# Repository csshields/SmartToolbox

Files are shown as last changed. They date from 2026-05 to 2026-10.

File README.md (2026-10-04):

# SmartToolbox

A toolbox that tells you which drawer a tool is in. Say what you are looking for, and
the box answers on its screen and lights the row of drawers to open.

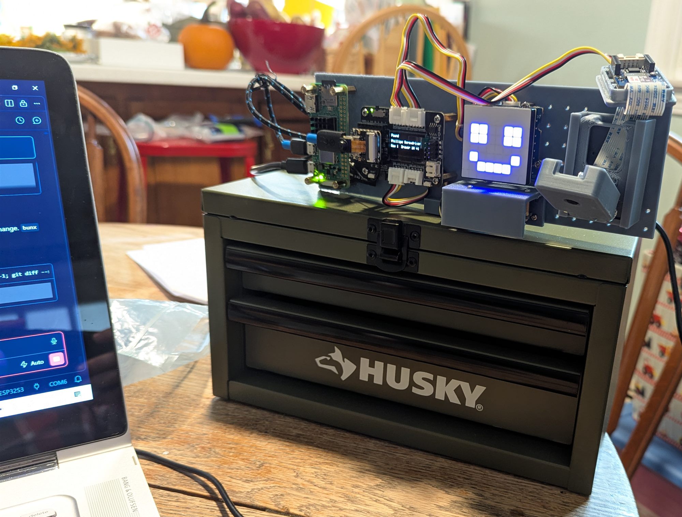
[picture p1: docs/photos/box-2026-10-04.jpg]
The SmartToolbox mounted on a Husky two-drawer chest, its screen naming a found Phillips screwdriver and its LED matrix showing a smiling face


*The build as of October 2026. More photos in [docs/photos](docs/photos/).*

## How it works

1. **Ask.** Hold the button and speak, or say **"Hi ESP"** and then the tool's name.
2. **Listen.** A Seeed XIAO ESP32S3 records the audio and sends it over USB to a
   Raspberry Pi Zero 2.
3. **Transcribe.** The Pi has the audio transcribed by Whisper, running on a NAS or
   through OpenAI, and matches what was said against the tools it knows -
   "where are my needle nose pliers" finds *Needle-Nose Pliers*.
4. **Answer.** The box shows the drawer on its OLED (for example `Row 1, Drawer 1A`),
   lights that row on its 8x8 LED matrix and LED strip, and its face reacts while it
   listens, thinks, and answers.

## What works today

| Feature | State |
|---|---|
| Voice lookup - button, speech, drawer on screen and lit | Working |
| "Hi ESP" wake word | Working since firmware 0.28.0 |
| Several toolboxes, each with its own drawers and light rows | Working |
| Web dashboard for toolboxes, drawers, tools and settings | Working |
| Firmware updates over Wi-Fi (OTA) | Working |
| Recovery flashing over USB from the Pi | Working |
| Recognising common tool names on the box itself, skipping Whisper | Planned |
| Waking up when someone walks up (PIR sensor) | Planned - the sensor is wired, nothing reads it yet |
| Noticing which tools leave and return (camera) | Blocked - needs a trained vision model |

The spec keeps a status tag on every section, and
[docs/HARDWARE.md](docs/HARDWARE.md) records what each physical part is doing.

## The dashboard

The Pi serves a web dashboard on port 3000:

- **Dashboard** - the tools in each drawer of a toolbox, with request history.
- **Toolboxes** - add toolboxes and drawers, edit a drawer's name, label and light row,
  and choose which box the device is mounted on.
- **Devices** - the XIAO's firmware version, last contact and recent activity.
- **AI Settings** - where speech goes to be transcribed.

A copy of the dashboard running on a development machine has its own database, and
shows a **Local copy** badge so it is not mistaken for the real box.

## Hardware

- Seeed XIAO ESP32S3 Sense (on-board microphone) on the Expansion Board Base for XIAO,
  which carries the OLED and the push-to-talk button
- Raspberry Pi Zero 2, connected to the XIAO by USB
- Grove 8x8 RGB LED matrix and Grove WS2813 LED strip
- Grove PIR motion sensor and Grove Vision AI V2 (wired, not yet used)
- 3D-printed mounting plate and brackets, in [cad/](cad/)

Pins, wiring, and the state of every part are in [docs/HARDWARE.md](docs/HARDWARE.md).

## Repository layout

```
smarttoolbox/
├── api/                 # Bun + TypeScript server and dashboard (runs on the Pi)
│   ├── src/             # Server, SQLite database, serial link, transcription
│   ├── public/          # Dashboard pages - plain HTML, CSS and JS, no build step
│   ├── scripts/         # Firmware release, USB flashing, device commands
│   ├── deploy/          # systemd service for the Pi
│   └── sync.ps1         # Deploys the server to the Pi
├── firmware/            # Arduino sketch for the XIAO ESP32S3
├── cad/                 # Printed parts, with the source that generates them
└── docs/                # Hardware record, plans, sources and photos
```

## Getting started

### Run the server locally

```bash
cd api
bun install
bun run start    # http://localhost:3000
bun test
```

On Windows the serial link to the box does not start, so the server and dashboard run
fine with nothing attached - against their own local database.

### Deploy to the Pi

```powershell
cd api
.\sync.ps1           # copy the server to the Pi and restart it
.\sync.ps1 -Status   # service status and the end of its logs
```

### Firmware

The sketch builds with `arduino-cli` against the pinned versions in
`firmware/smarttoolbox/sketch.yaml`. Releases go out over Wi-Fi:

```powershell
cd api\scripts
.\release-firmware.ps1 -Version x.y.z -Push -Now   # the device fetches it within a minute
.\flash-device.ps1 -Version x.y.z                  # over USB, when OTA cannot help
```

A change to the flash partition table, such as the one that made room for the wake
word, can only be installed over USB.

## Documentation

- [.github/copilot-instructions.md](.github/copilot-instructions.md) - the project spec:
  architecture, database, every endpoint, the serial protocol, and debugging.
- [docs/HARDWARE.md](docs/HARDWARE.md) - every part, its pins, and whether it works.
- [docs/](docs/) - implementation plans (`PLAN-*.md`), each with its current status.
- [firmware/README.md](firmware/README.md) - firmware setup.

## License

[MIT](LICENSE). The vendored Grove matrix driver in `firmware/smarttoolbox/` keeps
Seeed's own MIT licence, alongside it.

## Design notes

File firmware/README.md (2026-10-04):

# SmartToolbox Firmware

Arduino firmware for the Seeed XIAO ESP32S3 Sense that sits on the toolbox. It listens
for a request, sends the audio to the Pi over USB serial, and shows the answer on the
OLED, the 8x8 matrix and the LED strip.

Pins, wiring and the state of every part are in [docs/HARDWARE.md](../docs/HARDWARE.md).
The hardware traps worth knowing before changing anything are in
[.github/instructions/xiao-esp32s3-firmware.instructions.md](../.github/instructions/xiao-esp32s3-firmware.instructions.md).

## Hardware

- **Board**: Seeed XIAO ESP32S3 Sense, seated in the Expansion Board Base for XIAO
- **Carrier**: the Expansion Board Base brings the OLED (SSD1306, 0x3C), the
  push-to-talk button on D1, an RTC, an SD slot, and four Grove ports
- **Microphone**: the Sense board's PDM mic (GPIO 42 clock, GPIO 41 data). It feeds
  both push-to-talk and the "Hi ESP" wake word, and needs `PSRAM=opi` in the build
- **Indicators**: Grove 8x8 RGB LED matrix on a Grove I2C port; Grove WS2813 LED strip
  on the UART port, data GPIO44
- **Wired, not yet used**: Grove PIR motion sensor on the A0/D0 port (GPIO1), and the
  Grove Vision AI V2 on a Grove I2C port (0x62)
- **Link to the Pi**: USB serial to a Raspberry Pi Zero 2

## Building

The sketch builds with `arduino-cli`. `smarttoolbox/sketch.yaml` pins the ESP32 core
(3.3.11) and every library, and is the default profile, so a plain compile uses those
exact versions rather than whatever is installed on the machine:

```powershell
arduino-cli compile firmware/smarttoolbox
```

Libraries, all pinned in `sketch.yaml`:

- `ArduinoJson` - the serial messages
- `U8g2` - the OLED
- `Adafruit NeoPixel` - the WS2813 strip

The Grove matrix driver is not in the Arduino library registry, so it is vendored into
the sketch folder (`grove_two_rgb_led_matrix.*`). `ESP_SR` (the wake word), `ESP_I2S`,
`WiFi`, `HTTPClient` and `Update` ship with the ESP32 core.

`smarttoolbox/partitions.csv` replaces the board's default flash layout to make room
for the 3.3 MB speech model the wake word needs. Arduino picks it up from the sketch
folder automatically.

## Getting a build onto the device

Normally over Wi-Fi, from the `api/scripts` folder:

```powershell
.\release-firmware.ps1 -Version x.y.z -Push -Now   # the device fetches it within a heartbeat
.\flash-device.ps1 -Version x.y.z                  # over USB from the Pi, when OTA cannot help
```

Over-the-air updates need working firmware to receive them, and cannot change the
partition table. A bad build, or a partition change, goes on with `flash-device.ps1`,
which flashes through the XIAO's ROM bootloader over the USB cable it already shares
with the Pi. The `firmware-release` skill in `.claude/skills/` walks through all three.

Bump `FIRMWARE_VERSION` in `smarttoolbox.ino` for every release; the device compares it
with what the Pi offers.

## Talking to the Pi

The XIAO and the Pi exchange newline-delimited JSON over USB serial at 115200 baud. The
Pi sees the XIAO as `/dev/ttyACM0` and the `smarttoolbox` service opens it on start.
The device sends a `device/status` heartbeat every 30 seconds, which is how the Pi
knows it is alive and how it hands over queued commands such as "check for firmware".

To watch it:

```bash
tail -f ~/smarttoolbox/logs/service.log
```

```text
[serial] request id=status-12 endpoint=device/status
[serial] response written id=status-12
```

If the XIAO is unplugged, reset, or reflashed, the serial link reconnects on its own
with a growing backoff capped at 5s - no service restart needed. The full protocol is
in the spec.

## Project structure

```
firmware/
├── smarttoolbox/
│   ├── smarttoolbox.ino            # The firmware
│   ├── sketch.yaml                 # Pinned core and library versions
│   ├── partitions.csv              # Flash layout, with room for the speech model
│   ├── grove_two_rgb_led_matrix.*  # Vendored matrix driver
│   ├── arduino_secrets.example.h   # Template - copy to arduino_secrets.h
│   └── arduino_secrets.h           # Wi-Fi and device key (gitignored)
└── README.md                       # This file
```

`arduino_secrets.h` must live beside the sketch: Arduino resolves `#include "..."`
from the sketch folder only.

### Arduino Cloud leftovers

`Untitled_apr15a.ino`, `motion_ino.ino`, `thingProperties.h`, `sketch.json`, and
`ReadMe.adoc` sit in `firmware/` and are **history, not live code**. They came from
an early Arduino Cloud project and nothing builds or references them.
`motion_ino.ino` is the one worth keeping for now: it is the PIR + OLED bring-up
sketch, and its `U8G2_SSD1306_128X64_NONAME_F_HW_I2C` constructor is where the
working OLED setup came from. The rest can be deleted whenever you like.

## TODO

- [x] USB serial link to the Pi, with lookups and a heartbeat
- [x] Push-to-talk voice lookup
- [x] "Hi ESP" wake word (0.28.0)
- [x] Wi-Fi OTA updates, and USB recovery flashing
- [ ] Recognise common tool names on the device, skipping Whisper
- [ ] Read the PIR on GPIO1 (wired, no firmware)
- [ ] Talk to the Grove Vision AI V2 (needs a trained model first)

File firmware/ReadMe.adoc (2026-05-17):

:Author: shieldsfam01
:Email:
:Date: 15/04/2026
:Revision: version#
:License: Public Domain

= Project: {Project}

Describe your project

== Step 1: Installation
Please describe the steps to install this project.

For example:

1. Open this file
2. Edit as you like
3. Release to the World!

== Step 2: Assemble the circuit

Assemble the circuit following the diagram layout.png attached to the sketch

== Step 3: Load the code

Upload the code contained in this sketch on to your board

=== Folder structure

....
 sketch123                => Arduino sketch folder
  ├── sketch123.ino       => main Arduino file
  ├── schematics.png      => (optional) an image of the required schematics
  ├── layout.png          => (optional) an image of the layout
  └── ReadMe.adoc         => this file
....

=== License
This project is released under a {License} License.

=== Contributing
To contribute to this project please contact: 

=== BOM
Add the bill of the materials you need for this project.

|===
| ID | Part name      | Part number | Quantity
| R1 | 10k Resistor   | 1234-abcd   | 10       
| L1 | Red LED        | 2345-asdf   | 5        
| A1 | Arduino Zero   | ABX00066    | 1        
|===

=== Help
This document is written in the _AsciiDoc_ format, a markup language to describe documents. 
If you need help you can search the http://www.methods.co.nz/asciidoc[AsciiDoc homepage]
or consult the http://powerman.name/doc/asciidoc[AsciiDoc cheatsheet]

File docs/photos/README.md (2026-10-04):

# Photos

Photographs of the box as it was built, one file per occasion, named
`<what>-<yyyy-mm-dd>.jpg`. Resize to about 2000 px on the long side before
committing - a phone's full-size original is several megabytes and the repo
keeps every version forever.

| Photo | Shows |
|---|---|
| `wiring-2026-09-02.jpg` | The 2026-09-02 rewire, every Grove port populated. The wiring that `docs/HARDWARE.md` describes. |
| `box-2026-10-04.jpg` | The latest build, mounted on the Husky two-drawer box: Pi Zero 2 on the left, the XIAO on its expansion base with the OLED showing a found Phillips screwdriver, the 8x8 matrix smiling, and the Vision AI V2 in its printed cradle on the right. Taken the day "Hi ESP" was first proven. |

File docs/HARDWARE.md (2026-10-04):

---
title: Hardware - parts, bring-up status, and pin mappings
scope: the single record of what is in the box, what physically works, and which pin carries it
status: active
updated: 2026-09-13
---

# SmartToolbox Hardware

Every part owned, whether it physically works, and which pin carries it.
`.github/copilot-instructions.md` remains the project spec; it points here instead of
repeating any of this. The same status convention applies - see Document Conventions in
the spec - and note the spelling difference it records: a section carries
`**Status: ...**`, a component entry carries `**Status**: ...` with the asterisks closed.

Photographs of the box live in `docs/photos/`, dated, with an index there.
`wiring-2026-09-02.jpg` shows it as wired below; `box-2026-10-04.jpg` is the latest
build, mounted on the toolbox. When the words and a photograph disagree, check the
photograph's date before trusting either.

Firmware traps that are about *behaviour* rather than parts - touch sensor v2 semantics,
the first ten `touchRead` calls after boot, upload settings - live in
`.github/instructions/xiao-esp32s3-firmware.instructions.md`, which loads by file glob
when a sketch is open. Which pin carries what is here; how it misbehaves is there.

## The 2026-09-02 rewire

The box was taken apart and rebuilt on 2026-09-02. Everything below the bring-up table
describes the result. What changed, because several of these had been treated as fixed
constraints for weeks:

- **The Vision AI V2 came off the expansion header** and is now cabled to a Grove I2C
  port. It was never mechanically required to stack; that was convenience, and Seeed's
  own documentation offers the Grove route.
- **The Expansion Board Base took the header instead**, which is what unblocked every
  GPIO part in one move.
- **The Grove I2C Hub and the Grove Red LED Button came out of the box entirely.** The
  hub is unnecessary now the base carries two I2C ports, and the button was the
  mis-wired part that had been disturbing the bus.
- **The Grove OLED came off** in favour of the base's own screen, which the firmware
  drove with no change at all.
- **The WS2813 strip and the PIR are wired for the first time.**
- **The touch pad stopped being the trigger**, because the PIR now drives that pin. The
  base's button replaced it.

## Bring-Up Status

Updated 2026-09-02, with the Grove Base Hat row added 2026-09-06. This table is the
single place to check what is physically working. Each row is a summary; the detail
lives in the section named beside it.

| Component | Status | Notes |
|---|---|---|
| XIAO ESP32S3 Sense | Verified | Seated in the Expansion Board Base with the Sense board still mated on top. LED on GPIO21, active-low |
| Expansion Board Base | Verified | On the expansion header. Carries the OLED, the button, an RTC and an SD slot, and all four Grove ports now in use |
| USB serial XIAO to Pi | Verified | Unchanged by the rewire. The XIAO's own USB-C stays exposed with the base fitted |
| Wi-Fi OTA updates | Verified | Device pulled and installed 0.24.0. Signal measured at -52 dBm on 2026-09-02, so the external antenna is fitted and working. **Without it the radio cannot associate** |
| OLED | Verified | The base's own SSD1306 at 0x3C, on the shared bus. It replaced the Grove SSD1315, which answered at the same address - the two cannot both be on the bus. Same U8g2 constructor, no firmware change |
| Grove 8x8 matrix | Verified | On one of the base's Grove I2C ports, no longer through the hub. Mounted a quarter turn out, so the firmware sets `DISPLAY_ROTATE_270` every boot - that setting lives on the panel and survives power cycles |
| WS2813 LED strip | Verified, under-volted | Pointed at a real drawer row on 2026-09-02, in 0.27.0. Data is GPIO44; see the strip section for how that was proven and why the supply is a problem |
| Push-to-talk button | Verified | The base's own button on D1, shipped in 0.24.0. Hold-to-talk confirmed end to end on 2026-09-02: press, speak, release, drawer on the screen and the row on the strip |
| Microphone (PDM, on the Sense board) | Verified for Whisper and the wake word | Reported ready on the 0.24.0 boot and carries speech to Whisper. Since 0.28.0 it also feeds ESP-SR, and **"Hi ESP" fired on hardware on 2026-10-04.** **Known thin:** the audio sits at 4-10% of full scale (that capture's rms was 52) - enough for WakeNet up close, and the first suspect if it stops firing from further away. Detail and the DC-bias trap are under Microphone |
| PIR motion sensor | Wired, no firmware | On the base's A0/D0 Grove port, so its signal is GPIO1. **Nothing in the firmware reads it.** No longer blocked, merely unwritten |
| Grove Vision AI V2 link | Cabled, unused | Moved from the expansion header to a Grove I2C cable. No firmware has ever talked to it - there is no SSCMA include in the sketch and no such library in `sketch.yaml` |
| SenseCraft model | Not deployed | **Blocks Feature 3.** Nothing to detect until a model is trained and flashed |
| Camera (OV2640, on the Sense board) | Not initialised | Physically fitted and facing up. The sketch carries no camera driver. Tool identification is the Vision AI V2's job, not this camera's |
| Grove I2C Hub | Removed | Out of the box. The base's two I2C ports made it unnecessary |
| Grove Red LED Button | Removed | Out of the box. It was mis-wired into the I2C hub, where its switch pulled on lines the displays depend on. The base's own button does its job now |
| Touch pads | Unused | Still on the board and still touch-capable, but nothing reads them. GPIO1 carries the PIR |
| Grove Base Hat for Pi Zero | Owned, not fitted | Added to the list 2026-09-06. Never mounted, never powered, no software has addressed it. It would occupy the Pi's 40-pin header |
| Pi 40-pin GPIO header | Free, unpopulated | 26 usable GPIO, nothing in this project uses them. `gpioget`/`gpiomon` are installed and `/dev/gpiochip0` is present. The Grove Base Hat above is what would take it |
| Mounting magnets | Owned, not fitted | Added to the list 2026-09-13. Six 12 x 3 mm neodymium discs, intended to hold the back plate to the toolbox. Nothing holds them yet, and **the toolbox has not been checked for steel** - see Mechanical |

## Hardware Platform

**Main Controller**: Seeed **XIAO ESP32S3 Sense** (not the plain XIAO ESP32S3 - see
`docs/xiao-screenshot.PNG` for the exact part)

- **MCU**: Espressif ESP32-S3
- **Connectivity**: Wi-Fi and BLE are available; the box connects to the Pi Zero 2 over **wired USB serial** (USB-C, CDC/ACM). Wi-Fi is used only for OTA updates.
- **Memory**: 8MB PSRAM, 8MB flash. **PSRAM is on as of 2026-08-28**, and was off before that: a bare `esp32:esp32:XIAO_ESP32S3` takes the first entry of every board menu, and for PSRAM that is `disabled`, so `ps_malloc` returned null in every binary this repo had released. The fqbn now lives in `firmware/smarttoolbox/sketch.yaml` as the default `release` profile, so `release-firmware.ps1` and a bare `arduino-cli compile firmware/smarttoolbox` both pick it up; verify with `arduino-cli compile --show-properties`, where the bare fqbn shows an empty `build.defines` and the corrected one shows `-DBOARD_HAS_PSRAM`. **A manual `arduino-cli` invocation that bypasses the profile must carry `:PSRAM=opi` itself** - the microphone buffer cannot be allocated without it, and the failure presents as a dead mic rather than a build error.
- **Power**: 3.3V from the Pi's USB feed, through the base.

**Physical stack, as rebuilt 2026-09-02.** Three boards, three different connectors:

```
   Sense board          camera (OV2640) + PDM mic, facing up
        |               board-to-board connector
   XIAO ESP32S3         the core board
        |               expansion header
   Expansion Board Base OLED, button, RTC, SD, four Grove ports
```

The Vision AI V2 used to occupy the bottom slot and now hangs off a Grove cable instead.
The Sense board has never been in competition with anything: it mates through the XIAO's
own board-to-board connector, not the expansion header. This is the one place the stack
is described; everything else refers back to it.

**Expansion Board Base for XIAO with Grove OLED**, SKU 103030356

The carrier the XIAO plugs into, and the part that resolved the GPIO question. It brings
its own 0.96 inch SSD1306 OLED at 0x3C, a user button on D1, a buzzer on A3, a microSD
slot with chip select on D2, and a PCF8563 real-time clock at 0x51. It has a LiPo
connector, a charging circuit and a power switch, none of which this project uses -
**but the switch is a new way for the box to look dead, so check it first when nothing
happens.** The XIAO's own USB-C stays accessible with the base fitted; seat the XIAO
first, then plug the cable.

**Footprint, for the back plate**: the board is 58 x 42.5 mm with a 3.0 mm hole at each
corner, on a 50 x 35 mm rectangle - 4.0 mm in from the short edges and 3.75 mm from the
long ones. The v5 plate had these as M2 holes on a 50.8 x 38.1 pattern, measured by hand
on the assumption the board was imperial; both were wrong, and the board would not bolt
down. v6 in `cad/` uses the figures above, at 3.4 mm to leave the print some slack.

**Grove port allocation.** All four are in use, which is the whole budget:

| Port | Carries | Pins |
|---|---|---|
| I2C (1) | Grove Vision AI V2 | Shared bus, GPIO5/GPIO6 |
| I2C (2) | Grove 8x8 RGB matrix | Shared bus, GPIO5/GPIO6 |
| UART | WS2813 LED strip | GPIO44 data, GPIO43 backup |
| A0/D0 | Grove PIR motion sensor | GPIO1 |

**Every Grove port on this base supplies 3.3V**, which is silkscreened on the board. That
is correct for everything here except the strip, which wants 5V - see below.

**Vision Hardware**: Seeed Grove Vision AI Module (V2), SKU 101021112, + OV5647 Camera

- **Connection**: Grove I2C cable to the base, since 2026-09-02. It answers at address 0x62. Seeed documents both the header and the Grove route; stacking was convenience, not a requirement.
- **Onboard MCU**: Himax WiseEye2 (capable of on-device ML inference)
- **Storage**: 32GB microSD card on the module itself
- **Library**: `Seeed_Arduino_SSCMA`, which **this project has never used.** The link has been verified with other software; no shipped firmware has ever addressed the module.

**Owned, not in the box**

- **Grove I2C Hub (6 Port)**: removed 2026-09-02, unnecessary now the base has two I2C ports.
- **Grove Red LED Button**, SKU 111020044: removed 2026-09-02. It is a passive switch and LED with no I2C chip, and it had been plugged into the I2C hub, where its two pins landed on SDA and SCL and pressing it disturbed the bus. The base's own button replaced it.
- **Grove OLED Display 0.96 inch (SSD1315)**: removed 2026-09-02, displaced by the base's own screen at the same I2C address.

**API Server**: Raspberry Pi Zero 2

- **CPU**: Broadcom BCM2710A1 (ARM Cortex-A53 @ 1GHz, quad-core)
- **Memory**: 512MB RAM
- **Storage**: MicroSD card (16GB+ recommended)
- **OS**: Raspberry Pi OS Lite (64-bit recommended)
- **Connectivity**: WiFi 802.11n, Bluetooth 4.2
- **Power**: 5V via micro-USB (2.5A minimum recommended)
- **GPIO**: 40-pin header, entirely unused. 26 usable pins; libgpiod installed. A Grove Base Hat for it is owned and not fitted - see below.
- **Purpose**: Host the Bun API server, the SQLite database, and the dashboard, and process tool identification requests.

### Grove Base Hat for Raspberry Pi Zero

Seeed Grove Base Hat for Raspberry Pi Zero, SKU 103030276. **Owned as of 2026-09-06 and
never fitted.** It has not been mounted, powered, or addressed by any software, so every
fact below comes from Seeed's documentation rather than from this box. Treat the whole
section as a lead until something here has been checked against the part.

It is the Pi-side answer to the question the Expansion Board Base answered on the XIAO
side: it turns a bare 40-pin header into Grove ports. It is the Pi Zero form factor, so
it fits the Zero 2, and it keeps 24 pins passed through.

- **Port count is disputed by the vendor's own pages.** Seeed's product title advertises 1 I2C, 1 UART, 2 digital, 4 analog and 1 PWM; Seeed's wiki for the same board lists three analog ports, labelled A0, A1 and A2. **Count them on the board before designing against them.**
- **The Grove ports are 3.3V**, and the wiki says plainly that 5V Grove modules will not work on it. **This does not solve the WS2813 supply problem.** The strip still needs its own regulated 5V, and it could not move to the Pi in any case - see the strip section, where the timing comes off the ESP32's RMT peripheral.
- **The analog ports are not GPIO.** They land on an onboard 12-bit ADC that the Pi reads over I2C, so an analog part costs a bus transaction rather than a pin. The chip is an STM32F030F4P6 on older boards and an MM32F031F6P6 on newer ones, and **the two answer at different addresses, 0x04 and 0x08.** The product page for this SKU says MM32. `i2cdetect -y 1` settles it, and it is the first thing to run once the hat is on.
- **Pin mapping, from the wiki and unverified against the part**: digital on BCM 5 and 16, PWM on BCM 12 and 13, UART on BCM 14 and 15, and the I2C port straight onto the Pi's own bus.
- **The UART Grove port is the Pi's serial console** by default, so anything plugged in there needs the console disabled first. The XIAO link is USB CDC and is not affected by this.
- **Nothing in this project needs it yet.** Every part that wanted a GPIO is on the XIAO, and the 2026-09-02 rewire freed the header that had been blocking them. What the hat buys is a second place to put a plain digital or analog part, now that the XIAO's four Grove ports are fully allocated. It is also a third answer to the constraint discussed under the MCP23017 in `docs/PLAN-drawer-activity.md` - though that plan dropped per-drawer switches over the cost of a magnet and a wire run on every drawer, which having somewhere to plug them does not change.

## Sensors & Peripherals

### WS2813 LED strip - the row indicator

Grove WS2813 RGB LED Strip Waterproof, 30 LED/m, 1m, SKU 104020108. On the base's UART
Grove port.

- **Data is GPIO44 (D7). The backup line is GPIO43 (D6).** Proven on hardware 2026-09-02 by a firmware bring-up that drove each pin in turn in a different colour and let the strip say which one it answered on. Neither Seeed's wiki nor the connector markings settled it, and Grove UART cables differ over which signal sits on pin one.
- **The pixel that lights at power-up is the boot ROM.** The ROM prints its log on GPIO43 before the sketch starts, that pin is the strip's backup input, and a WS2813 falls back to the backup line when the main one is idle. The first write from the firmware clears it. This is not a fault and it was visible long before any strip code existed.
- **Nothing in the firmware uses UART0**, so the pins are free. `Serial` is the native USB CDC port.
- **Library**: `Adafruit NeoPixel`, pinned in `sketch.yaml`. It drives the timing from the ESP32's RMT peripheral, which is why this works on the XIAO and would not have worked from a Grove port on the Pi.
- **Power is the open problem.** The base's Grove ports supply 3.3V and a WS2813 wants 5V, so the strip runs under-volted: colours skew, the top of the brightness range is missing, and the blue that lights most readily is the one with the most headroom. It works well enough to prove the wiring. **Before the strip is mounted it should get its own regulated 5V supply with a shared ground**, sized for up to 1.8A at full white, because thirty LEDs drawing through the XIAO's regulator on the Pi's USB feed is not a supply, it is a fuse waiting to be found.
- **Brightness is deliberately low** in firmware for the same reason. Raise it only after the supply is sorted.
- **Row mapping is a placeholder.** Row N lights LED N-1. Which LED ends up beside which drawer is a physical decision nobody has made, because the strip is still coiled on the bench.
- **Status**: **working.** In 0.27.0 a spoken lookup lights the LED beside the matching row. First proven 2026-09-02 by asking for a Phillips head screwdriver and watching LED 1 come up white, white being what a record with no confidence gets.

### Push-to-talk button

The Expansion Board Base's own button, on **D1 (GPIO2)**. It shorts the pin to ground
with no pull-up on the board, so the firmware holds it high internally and a press reads
LOW. Hold it, speak, release.

- **It replaced the D0 touch pad**, which the PIR now drives. Touch charges a pad while the sensor drives it, which is two drivers on one net.
- **The touch machinery went with the pad**: seven pads of baseline calibration, a trigger ratio, a warm-up discard, and a per-scan debug print, all of which existed to make a capacitive pad behave the way a button simply does. The traps they taught are still recorded in the firmware instructions, because the pads remain on the board.
- **Watch for it reading permanently pressed.** D1 is plausibly the second signal pin of the A0/D0 Grove port the PIR sits on. Single-signal Grove modules leave that pin unconnected, so it should be clear, but a box that starts recording on its own and never stops is that.
- **Status**: shipped in 0.24.0, confirmed on hardware 2026-09-02.

### Microphone (on board)

The XIAO's own digital microphone, on the **Sense expansion board**. No external part is
needed or planned.

- **Interface**: PDM. Pins are fixed by the board, confirmed against Seeed's own documentation: **GPIO 42 = clock, GPIO 41 = data.**
- **Sample Rate**: 16 kHz mono, 16-bit. Not a preference - the ESP32-S3 supports *only* PDM mono at 16-bit, so the bit width and slot mode are the chip's, not a choice. The rate is adjustable; Seeed reports 16 kHz as the stable one, and it is also what Whisper wants, so there is no reason to move it.
- **Library**: `ESP_I2S.h` from the installed esp32 core (3.3.11), *not* the core-2.x `I2S.h` that Seeed's published examples still lead with. The two have different APIs and picking the wrong page is the likely first failure:

```cpp
// Core 3.x - what this project has.
I2S.setPinsPdmRx(42, 41);
I2S.begin(I2S_MODE_PDM_RX, 16000, I2S_DATA_BIT_WIDTH_16BIT, I2S_SLOT_MODE_MONO);
```

- **Two ways to read, and they are not interchangeable.** `recordWAV(seconds, &size)` returns a `ps_malloc`'d buffer with a WAV header already attached, but takes a fixed duration - fine for a bring-up, useless for hold-to-talk, where the length is not known when recording starts. That path reads in a loop instead and lets the Pi write the header. See `docs/PLAN-mic-bringup.md` and `docs/PLAN-voice-lookup.md`.
- **Buffers go in PSRAM.** Four seconds of 16 kHz 16-bit mono is 128 KB against the XIAO's 320 KB of SRAM, of which this sketch already uses 49 KB.
- **The mic rides on a positive DC bias.** Samples run roughly +981 to +2568 and never cross zero, so RMS must be taken about the mean - measuring raw samples reads the offset, not the sound. Corrected in 0.17.0. A DC-corrected RMS read 17 in a quiet room against 210 spoken into, on 2026-08-29.
- **It feeds two consumers now, and they do not share.** Since 0.28.0 ESP-SR's feed task reads this same `I2SClass` continuously for the wake word, and the recording loop takes it back for the duration of a capture. Both traps that follow from that - draining the pause rather than trusting it, and the `portMAX_DELAY` the feed task leaves on the shared object - are in `.github/instructions/xiao-esp32s3-firmware.instructions.md`.
- **Status**: carrying speech since 0.20.0, voice lookup shipped in 0.22.0. Wake word written in 0.28.0 and **proven on hardware 2026-10-04**: "Hi ESP" started a capture that Whisper transcribed as "screwdriver". **Known thin:** the audio sits at 4-10% of full scale, with no gain applied and the DC offset not stripped. That was tolerable for Whisper and turned out to be enough for WakeNet at close range. It is still the weakness that makes the box mis-hear "screwdriver", and the first thing to look at if the wake word gets unreliable with distance.

### PIR motion sensor (Grove PIR Sensor, SKU 101020020)

- **Connection**: the base's A0/D0 Grove port, so the signal is **GPIO1 (D0)**. Wired 2026-09-02.
- **Type**: passive infrared, digital output, HIGH on motion. 3.3V-5V from the Grove port.
- **Detection Range**: configurable, typically 3-7 meters.
- **Board**: 40 x 20 mm, with three 2.2 mm mounting holes, **all centred on the board's edge** inside small round ears. Two are on the long edges, 10 mm from the connector end and 20 mm apart. The third is on the centreline of the sensor end. The PIR element itself sits 13.3 mm from the board centre, towards that end. These figures come from Seeed's Eagle board file for v1.2 (see `docs/SOURCES.md`). An earlier guess of two holes 5 mm in from each end was wrong, and so was the first bracket built on it.
- **Bracket**: `pir_bracket.stl`, reshaped 2026-09-27 and **not yet printed**. Seen from the side it is a C, open at the bottom: the upright bolts to the plate, a shelf runs forward off its top, and a hood hangs down the front. The board screws under the shelf facing down, inside the 26 mm channel, so the hood blocks the view forward into the room and the sensor looks down at the drawers. Nothing hangs below the plate's bottom edge, so nothing gets in the way of the top drawer. A PIR sees warm, moving things, so what it catches at the drawers is the hand and arm, not the drawer itself.
- **Status**: **wired and unread.** No firmware touches GPIO1. Feature 1 is no longer blocked on hardware; it is simply unwritten.

### Vision: Grove Vision AI Module (V2) + OV5647 Camera

- **Resolution**: OV5647, up to 5MP (2592x1944)
- **Connection**: Grove I2C cable to the base, address 0x62.
- **Identification Method (default)**: on-device inference on the module's WiseEye2 MCU via a model deployed through **SenseCraft AI** (no-code; supports MobileNet V1/V2, EfficientNet-lite, YOLOv5/v8). Only the label and confidence are read - Seeed's hardware cannot serve a live frame and results over the link at the same time. A cloud vision model remains a fallback, but it needs raw frames pulled a different way: the module's own SD card or its Type-C port.
- **Enclosure**: a printed three-part holder - base, tilting cap, camera holder - taken from Thingiverse rather than drawn here. Source and licence are under Printed parts in `docs/SOURCES.md`; it is CC BY-SA, so merging its geometry into a part of ours would carry that licence across. **It is superglued to the back plate.** The plate is on its sixth revision and will be reprinted again, and every reprint means breaking that bond or losing the enclosure, so a cradle bolting to the plate's 10 mm grid is the better fixing - see `cad/`.
- **Status**: **connected and unused.** No model is deployed, and no firmware in this repo has ever addressed the module. Both have to change before Feature 3 means anything.

### Camera (OV2640, on board)

On the Sense board, facing up. **No firmware has ever initialised it** and the sketch
carries no camera driver. Tool identification runs on the Vision AI V2's own camera and
MCU, so this one has no assigned job.

### IMU (external, TBD)

- **Type**: 6-axis (3-axis accelerometer + 3-axis gyroscope), I2C
- **Status**: no part selected, nothing bought. **Library**: TBD.

### Displays

**OLED**: the base's onboard 0.96 inch SSD1306 at 0x3C, on the shared I2C bus. Shows
status and exact drawer labels such as `1A` and `3`. Driven with U8g2
(`U8G2_SSD1306_128X64_NONAME_F_HW_I2C`).

**8x8 RGB matrix**: Grove, on a Grove I2C port. Six positions represent rows 1-6; row 1
is a single shared indicator for drawers 1A, 1B and 1C. Its address is discovered at boot
and confirmed against the VID, so a missing panel degrades rather than hangs. Superseded
in the long run by the strip - see the Row Indication decision.

**Camera illumination LED**: planned, not owned, not wired.

## Pin Mappings

**Status: Implemented** - every pin below is wired and confirmed on hardware, except
where the entry says otherwise.

```cpp
// Onboard user LED. Active-low: LOW turns it ON, HIGH turns it OFF.
#define LED_PIN           LED_BUILTIN   // GPIO21

// Push-to-talk: the expansion base's own button, switch to ground.
const uint8_t BUTTON_PIN = 2;           // D1

// WS2813 strip on the base's UART Grove port. DIN is the RX pin; the boot ROM's
// log lands on the TX pin, which is the strip's backup input.
const uint8_t STRIP_DATA_PIN = 44;      // D7, UART0 RX
//                              43      // D6, UART0 TX - backup in, driven by no one

// PDM microphone on the Sense board. Fixed by the board, not chosen.
#define MIC_CLOCK_PIN     42
#define MIC_DATA_PIN      41

// PIR motion sensor on the base's A0/D0 Grove port. Wired, and read by nothing.
//   GPIO1 (D0)

// I2C, shared by everything on the base's two Grove I2C ports plus the base's own
// devices. `Wire.begin()` needs no arguments.
//   SDA = D4 (GPIO5), SCL = D5 (GPIO6)
//   0x3C OLED (on the base)      0x51 RTC (on the base, unused)
//   0x62 Grove Vision AI V2      matrix address discovered at boot
```

### Also spoken for

The base wires these whether or not the firmware uses them, so treat them as taken:
**D2** is the microSD chip select, **A3** is the buzzer, and **D8/D9/D10** are the SPI
bus the SD slot sits on. The buzzer is the only sound hardware this project owns.

### Deliberately Absent

- **No per-row LED GPIO pins.** Row indication is the strip on a single data line, and the matrix over I2C. Earlier drafts defined `ROW_LED_1`..`ROW_LED_6`; those defines should not reappear.
- **No touch pad defines.** The pads are still on the board and nothing reads them.
- **No per-drawer sensors.** Drawer open/close detection is one of three candidate methods in Feature 3 and no hardware has been chosen.

## Resolved: the GPIO expansion question

**Closed 2026-09-02.** For weeks this section asked where the PIR and a button could
possibly go, on the premise that the Vision AI V2 owned the expansion header and could
not be moved. Both halves of that premise were wrong, and the correction cost a Grove
cable:

- **The module did not need to stack.** It is an I2C peripheral at 0x62 and Seeed's own documentation offers the Grove route. The proof was already sitting in the old build, where the I2C hub chained off the module's own Grove port - the bus was coming back out of that connector the whole time.
- **The header was better spent on the Expansion Board Base**, which turns one occupied slot into four Grove ports, a button, a screen and a clock.

Two earlier corrections in this section are worth keeping, because both had been shaping
decisions:

- **GPIO never had to come from the XIAO.** The Pi's 40-pin header is unused. That option was never taken, but it was the observation that unstuck the thinking.
- **The Sense board never competed with anything.** It mates through the XIAO's own board-to-board connector. An earlier revision of the spec claimed otherwise and that claim drove decisions for weeks.

What is still constrained: the base has one digital Grove port and the PIR has it, so
another digital part means the Pi's header, a soldered wire, or the buzzer's pin. As of
2026-09-06 the first of those has a Grove-shaped answer sitting unused in a drawer - see
the Grove Base Hat for Raspberry Pi Zero above.

## Decision: row indication runs on the strip, driven from the XIAO

**Status: Partial** - decided 2026-08-28, moved to the XIAO 2026-09-02, code written and
not yet released. **This reverses the earlier decision to drive the strip from the Pi
over SPI**, which was made when the XIAO's expansion header looked unavailable. Once the
base freed a real GPIO, the Pi route lost every argument it had:

- The ESP32 generates WS2812 timing in its RMT peripheral. On the Pi the same job needs either a native addon this project does not want inside Bun, or a bit-banging trick over SPI on a pin that is not a Grove port.
- The protocol argument was a wash. The Pi route needed no new message because the Pi computes the `rows` array; the XIAO route needs none either, because that array is already delivered to the device and already lights the matrix.
- One fewer moving part, and the strip lights from the same code path as every other indicator.

The reason for using a strip at all is unchanged. The 8x8 matrix indicates a row by
lighting matrix row N for toolbox row N, which has two faults that are the same fault
seen from two sides:

- **It caps at eight.** The unit of meaning is the panel's own height, so a toolbox with more rows than the panel has cannot be addressed. `MAX_TOOLBOX_ROWS` is 8 for this reason - a symptom of the design, not a hardware limit worth keeping.
- **It is hard to read.** A single lit row gives the eye no scale to count against, so it reads as "higher" or "lower" rather than as row 3.

The strip removes both by not encoding position at all. One LED sits beside each row, so
the light **is** the answer. Thirty LEDs is thirty rows.

**What this does to the other outputs.** Each ends up with one job and no overlap:

| Output | Job |
|---|---|
| WS2813 strip | Points at the row, physically |
| 8x8 matrix | The face: idle, thinking, not found, not understood |
| OLED | Names the exact drawer - `1A` against `1B`, which the strip cannot distinguish |

The lit-row phase is already gone - a result goes straight to the digit, because the
strip is the spatial cue now. Once the strip is mounted the matrix stops encoding
numbers at all, so the digit phase can go too. Do not invest further in making the
matrix legible as a row indicator.

## Mechanical

The printed parts - the back plate, the PIR bracket and the Vision AI cradle - are
generated by `cad/build_plate.py`, which is their source of record. The plate is
228.6 x 76.2 x 3.0 mm with a 10 mm grid of M2 clearance holes; the bottom two rows of
that grid run on to the right edge so the PIR bracket can bolt anywhere along the
bottom. Component footprints that the CAD depends on are recorded with their component
above - the expansion board's is under Expansion Board Base.

### Mounting magnets

- **What is owned**: six neodymium disc magnets, 12 mm diameter x 3 mm thick. Grade not
  marked, so treat the pull as roughly 2 kg each until something says otherwise. Four
  would mount the plate and two are spare.
- **They cannot sit in the plate.** The magnet is 3 mm thick and the plate is 3.0 mm
  thick, so there is no pocket to cut. They go in `magnet_bar.stl` instead: a 20 x 76.2
  x 4.8 mm bar that bolts to the back of the plate and carries a magnet near each end.
  Two bars, one per plate end, put four magnets near the plate's four corners. It is
  one part printed twice - the bar is symmetric about its own centreline, so the left
  and the right are the same STL.
- **Each pocket is 0.2 mm shallower than the magnet**, so the magnet stands proud and
  touches the steel. Plastic between magnet and steel is an air gap, and an air gap
  costs pull far faster than a thicker wall would. The bolt pilots are blind for the
  same reason: a screw tip breaking through would hold the magnet off.
- **Where the bars bolt, and why those columns.** Grid rows 25 and 45, on columns 44 and
  184. 184 is the rightmost full grid column - the rail past it carries rows 5 and 15
  only, too short a base for a 76 mm bar. 44 is the leftmost column with room for a
  screw head: the Pi ends at 34.5 and the expansion board starts at 52. That column is
  the only thing v6 gained for this; the right bar bolts to holes that existed in v5.
- **Budget the pull as shear, not pull.** The plate hangs on a vertical surface, so the
  magnets work in shear, which holds on the order of a fifth of the rated figure - and
  the rated figure assumes thick ground steel rather than thin painted toolbox sheet.
  Against the 300-400 g the loaded plate weighs, four of these is comfortable; one is
  not.

### Feet

`foot.stl`, printed twice, **drawn 2026-09-27 and not yet printed.** The alternative
to the magnets: the plate stands on top of the toolbox rather than hanging on its side,
landscape, Pi end on the left.

- **The plate leans back 8 degrees** in a 3.4 mm slot. The lean is what holds it: the
  plate rests against a 22 mm triangle behind, and a 6 mm lip in front only stops the
  bottom edge sliding forward. The slot is loose on purpose, so nothing depends on
  friction or on how accurately the plate printed.
- **The tilt is kept slight** because the PIR and the camera tip back with the plate.
  At 8 degrees both still look down at the drawers.
- **The plate stands at the lid's front edge.** The PIR looks straight down from about
  16 mm in front of the plate, so the plate has to be near the edge for the sensor to see
  past the lid to the drawers. That is why the front of the foot is only 6 mm deep and
  the heel behind is 35. It also means the
  forward tipping margin is small: the camera and the PIR sit in front of the plate. If
  the plate tips forward, raise `FOOT_TILT` before lengthening the toe.
- **Where they go**: plate x 62-92 and 196-226. That keeps them clear of both magnet-bar
  columns, so feet and bars can be tried together. It also clears the PIR bracket at
  119-169 and the expansion board's screw heads at x 56 and 106.

## Open items

1. **A 5V supply for the strip**, with a shared ground. Until then it stays dim and
   under-volted.
2. **Mount the strip and fix the row mapping.** `STRIP_ROW_FIRST_LED` and the row-to-LED
   arithmetic are placeholders until the physical layout exists.
3. **Give the microphone some gain.** The audio sits at 4-10% of full scale with the DC
   offset not stripped, and it mis-hears: "screwdriver" came back from Whisper as "We're
   screwing driver" on 2026-09-02, and the box correctly found nothing for it. The fix is
   Step 1 of `docs/PLAN-mic-bringup.md`, and it is now the weakest link in the box.
   **Raised in importance 2026-09-06:** the 0.28.0 wake word runs WakeNet on this same
   signal, and WakeNet is fussier than Whisper. If "Hi ESP" needs shouting, this is why,
   and this is the fix - not the recording path.
4. **Say "Hi ESP" at the box.** The 0.28.0 wake word is written, compiles, and has never
   been heard by anything. It needs a partition change, so it goes on over USB with
   `flash-device.ps1` and cannot arrive over the air. Say it **twice** - the second time
   is the test, because ESP-SR disables itself after every detection and a missing re-arm
   looks exactly like a dead microphone.
5. **Read the PIR.** It is wired and nothing looks at it, which is all that stands
   between here and Feature 1.
6. **Deploy a SenseCraft model**, without which the Vision AI V2 is a connected part with
   nothing to say.
7. **Check the toolbox is actually steel**, before any more design goes into magnet
   mounting. A fridge magnet against the spot the plate will sit answers it. Plenty of
   toolboxes are aluminium or plastic-skinned, and the whole approach dies if this one
   is.

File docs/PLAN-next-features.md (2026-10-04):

---
title: Plan of Attack - Next Four Features
scope: implementation plan, written 2026-08-27
status: partially complete - Features 1, 2 and 3 are done; 4 is not started
---

> **Features 1, 2 and 3 shipped 2026-08-27.** Read those sections below as history,
> not as work outstanding. Feature 4 (dashboard search) is still an accurate
> description of unstarted work.
>
> Feature 1 (serial reconnect) needed a follow-up the plan did not anticipate: the
> reconnect worked, but the tty came up in cooked mode with echo, so the device
> received nothing back. See Communication Protocol in the spec.
>
> Feature 2 (touch-triggered lookup) took three hardware bugs beyond what is described
> here - the S3's touch readings rise rather than fall, scanning all nine pads froze the
> peripheral, and the startup baseline averaged unusable boot readings. All three are
> recorded in `.github/instructions/xiao-esp32s3-firmware.instructions.md`.
>
> Also built the same day, and not part of this plan: Wi-Fi OTA updates, see
> `PLAN-ota-updates.md`.

# Plan of Attack

Four features, ordered. Each is independent except where noted — you can implement any
one without the others, but the ordering below minimizes wasted effort.

| # | Feature | Size | Touches | Hardware needed |
|---|---|---|---|---|
| 1 | Serial reconnect | Small | API | None |
| 2 | Touch-triggered lookup | Medium | Firmware + API | XIAO only (already verified) |
| 3 | Delete endpoints | Small | API + dashboard | None |
| 4 | Dashboard search | Small | Dashboard | None |

**Recommended order: 1 → 2**, then 3 and 4 in either order. Feature 1 is first because
every `arduino-cli upload` resets the board and re-enumerates the USB device, which
kills the Pi's serial stream. Without reconnect, every firmware iteration in Feature 2
costs a `sudo systemctl restart smarttoolbox`. Doing 1 first pays for itself within an
hour of Feature 2 work.

If you want a lighter second item instead, swap Feature 2 for 3 or 4 — nothing depends
on ordering beyond the note above.

---

## Shared conventions

Read `.github/copilot-instructions.md` first; it is the project spec and is current as
of 2026-08-27.

**Code style**
- TypeScript strict mode is on (`api/tsconfig.json`). No `any` — the codebase casts
  request bodies to explicit inline types instead, e.g.
  `await readJsonBody(req) as { name?: string }`.
- The router in `api/src/index.ts` is a plain `if` chain on `pathname` and
  `req.method`, not a framework. Hono is a dependency but is **not** used for routing.
  Match the surrounding pattern; do not introduce Hono to add a route.
- All SQL lives in `api/src/db.ts` as prepared statements declared at module scope.
  Parameterized queries only (`?1`, `?2`).
- Errors propagate as thrown `Error`s from `db.ts`, and `index.ts` maps the message to
  a status code — see the `message === 'Drawer not found.' ? 404 : 400` pattern at
  `api/src/index.ts:427`. Keep that pattern rather than inventing an error class.
- Every mutating route calls `writeRequestLog(...)`, which both persists to
  `request_logs` and console-logs. Follow it; the dashboard's Recent Requests panel
  reads that table.
- Comments are sparse in this codebase and explain *why*, not *what*. Match that.

**Testing**
- `bun test` from `api/`. Two test files exist: `serialProtocol.test.ts` and
  `serialTransport.test.ts`, both using `import { expect, test } from "bun:test"`.
- There is **no `test` script in `package.json`** — add
  `"test": "bun test"` to `scripts` as part of Feature 1.

**Running**
- `cd api && bun run start` → `http://localhost:3000`.
- On Windows the serial listener does not start (`SERIAL_DEVICE` is unset off Linux),
  so the HTTP API and dashboard run fine with no XIAO attached.
- Deploy to the Pi: `cd api && .\sync.ps1`. Add `-Status` to see service status and the
  tail of both logs.

**Documentation is part of done.** `.github/copilot-instructions.md` uses per-section
status tags (`**Status: Implemented | Partial | Planned | Blocked**`). Each feature
below lists which tags and checklists to update. Update them in the same commit as the
code — that convention is the whole point of the tags.

---

## Feature 1 — Serial reconnect

### Why

`api/src/serialTransport.ts:22` opens the device exactly once:

```ts
const input = createReadStream(options.devicePath);
const output = createWriteStream(options.devicePath, { flags: "a" });
```

When the XIAO is unplugged, reset, or reflashed, the read stream errors or closes and
never comes back. `README.md` currently documents the workaround: restart the service.
That workaround is the thing being deleted.

### Design

Wrap the stream creation in a `connect()` function and drive it from a small state
machine:

- `connect()` creates both streams, wires handlers, and resets the line buffer.
- On `error` **or** `close`/`end` from either stream: tear down both, then schedule a
  reconnect. Guard with a flag so `error` followed by `close` schedules only once.
- Backoff: start at 500ms, double on each failure, cap at 5s. Reset to 500ms once a
  connection successfully delivers data.
- `close()` must set a `stopped` flag and clear any pending reconnect timer, otherwise
  tests and shutdown hang.
- **Reset `SerialLineBuffer` on every reconnect.** A partial line captured before an
  unplug is garbage and would corrupt the first message after reconnect.
- A missing device (`ENOENT`, XIAO not plugged in at boot) is the same case as a
  disconnect — retry, do not throw. This also means the service can start before the
  XIAO is attached.

### Make it testable

The current signature takes `devicePath` and calls `fs` directly, which cannot be
tested without hardware. Add optional injection:

```ts
openStreams?: (devicePath: string) => { input: Readable; output: Writable };
retryDelaysMs?: number[];   // default [500, 1000, 2000, 4000, 5000]
```

Default to the real `fs` implementation. Tests pass fake streams (`PassThrough`) and
`[1, 1]` delays, so no fake timers are needed.

### Steps

1. Add `"test": "bun test"` to `api/package.json` scripts.
2. Refactor `startSerialTransport` into `connect()` + reconnect scheduling, keeping the
   exported signature backward compatible (all new options optional).
3. Add `onConnect` / `onDisconnect` optional callbacks alongside the existing
   `onError` and `onResponseWritten`.
4. Wire the new callbacks in `api/src/index.ts:534` to log
   `[serial] connected` / `[serial] disconnected, retrying in Nms`.
5. Extend `serialTransport.test.ts`: the existing `SerialLineBuffer` test stays; add
   coverage for (a) reconnect after an input error, (b) buffer reset across reconnect,
   (c) `close()` cancelling a pending retry.

### Gotchas

- The `input.on("data", async ...)` handler at `serialTransport.ts:26` is async but data
  events are not queued — two chunks arriving quickly can interleave responses. Out of
  scope here, but do not make it worse; note it if you touch that path.
- Writing to a disconnected device can throw synchronously as well as emit `error`.
  Wrap the `output.write` call.

### Done when

- Unplug the XIAO mid-run, replug it, press `RST`, and `[serial] request id=boot-1`
  appears in the log with no service restart.
- `bun test` passes.
- `README.md` "USB Serial Check" section: delete the restart-required paragraph.
- `.github/copilot-instructions.md`: tick "Serial reconnect" in Phase 2 of Development
  Priorities.

---

## Feature 2 — Touch-triggered tool lookup

### Why

This is the first time the system does its actual job. Every piece already works in
isolation: touch pads are verified on hardware, the serial handshake reaches the Pi,
and `tools/lookup` is implemented end to end on the API side. Nothing has ever
connected them.

No new hardware. No microphone, no SenseCraft model, no I2C hub.

```
touch pad → tools/lookup over serial → SQLite → response → LED blinks row number
```

A touch pad is a stand-in for the microphone that does not exist yet. Each pad maps to
a hardcoded tool name; this is a bench harness for the real voice flow in Feature 2 of
the spec, not the finished interaction.

### Prerequisite: seed the database

The lookup returns nothing useful against an empty database. Before bench testing,
create a drawer and a tool from the dashboard, matching the real box (see Physical
Layout in the spec): e.g. drawer `1A` in row 1 containing "phillips screwdriver".
The firmware's hardcoded query must match a tool name exactly — see the matching
caveat under Feature 4.

### API side (small)

One change, in `api/src/index.ts:158`:

`handleSerialLine` currently returns an error response for **any** unparseable line.
The firmware also emits human-readable debug output on the same wire
(`Serial.print("Touched GPIO: ")` in the current sketch), so every debug line would
generate an error response written back to the device — noise generating noise.

Rule to implement:

- Line does not start with `{` after trimming → **ignore silently**. It is device debug
  output, not a request.
- Line starts with `{` but fails to parse → return the existing error response. A
  malformed request is still a bug worth reporting.

Add a test in `serialProtocol.test.ts` or a new test covering both branches.

### Firmware side

Current state: `firmware/smarttoolbox/smarttoolbox.ino` in the working tree is the
touch/LED bring-up sketch. The committed version is the boot handshake. This feature
merges them.

1. **Add ArduinoJson** via Library Manager. Update the checklist in the spec's
   Libraries Required section.
2. **Restructure `loop()` to be non-blocking.** The bring-up sketch ends with
   `delay(50)`, which starves serial reads. Convert to a `millis()`-based poll
   interval, keeping the existing debounce (2 consecutive samples) and the
   startup-calibrated touch baselines — that calibration is deliberate, see
   `.github/instructions/xiao-esp32s3-firmware.instructions.md`.
3. **Map pads to tools.** A small array parallel to `TOUCH_PINS`, e.g. pad D0 →
   `"phillips screwdriver"`. Only map as many pads as you have seeded tools.
4. **Send the request.** Monotonic id counter (`req-1`, `req-2`, ...):
   ```json
   {"id":"req-1","type":"request","endpoint":"tools/lookup","body":{"query":"phillips screwdriver"}}
   ```
   One line, newline-terminated. Note `body` is required by the parser even when empty.
5. **Read the response.** Mirror `SerialLineBuffer`: accumulate `Serial.read()` bytes
   until `\n`, then parse with ArduinoJson. Match on the echoed `id`; ignore responses
   whose id you are not waiting for. Time out after ~2s and treat as not-found.
6. **Blink feedback.** The LED is active-low (`LOW` = on). There is no matrix yet, so
   encode the result in blink count:
   - found → blink `rows[0].rowNumber` times, slow
   - not found (`found: false`, HTTP 200 — a miss is not an error) → 3 fast blinks
   - timeout or error response → 1 long blink

   Document in a comment that this stands in for the 8x8 matrix.
7. **Remove or gate the periodic debug prints** so they do not flood the protocol
   channel. The API-side rule above tolerates them, but they are still noise.

### Response shape to parse

```json
{"id":"req-1","success":true,"body":{
  "found": true,
  "tool": "Phillips Screwdriver",
  "drawers": [{"drawerId":1,"label":"1A","rowNumber":1,"quantity":2,
               "confidence":null,"observedAt":null}],
  "rows": [{"rowNumber":1,"certainty":null}]
}}
```

`confidence` and `certainty` are `null` for manually entered tools that the camera has
never observed. Do not assume they are numbers.

### Gotchas

- **Serial baud is 115200** and the board re-enumerates on reset — Feature 1 is what
  makes this tolerable.
- ArduinoJson document sizing: the response above is comfortably under 512 bytes for a
  single drawer, but a tool in several drawers grows it. Use `JsonDocument` (v7) which
  sizes dynamically, or budget 1KB.
- Touch baselines are captured in `setup()`. If a pad is being touched at boot the
  baseline is wrong — worth a serial warning, not a fix.

### Done when

- Touching a mapped pad blinks the LED the correct number of times for a seeded tool.
- Touching it for an unseeded tool gives 3 fast blinks.
- `[serial] request id=req-N endpoint=tools/lookup` appears in the Pi log.
- Spec updates: Hardware Bring-Up Status table (add a row for the touch-triggered
  lookup path), Phase 2 checklist ("Make the firmware send real requests" — adjust
  wording since this is `tools/lookup`, not `vision/observe`), and Feature 2's status
  line to note the bench harness exists.

---

## Feature 3 — Delete endpoints

### Why

The API has no `DELETE` route at all. A drawer created with a typo is permanent, and
the only recovery is deleting the SQLite file. `ON DELETE CASCADE` is already in the
schema and `PRAGMA foreign_keys = ON` is set at `api/src/db.ts:62`, so the database
side is ready.

### Steps

1. **`api/src/db.ts`** — two functions mirroring the existing style:
   - `deleteDrawer(drawerId: number): boolean` — returns whether a row was removed.
   - `deleteTool(drawerId: number, toolId: number): boolean`.

   Declare the `DELETE` statements at module scope with the other prepared queries.
   `bun:sqlite`'s `.run()` returns `{ changes }`; use it rather than a `SELECT` first.

2. **`api/src/index.ts`** — two routes, following the existing regex-match pattern at
   `api/src/index.ts:479`:
   - `/^\/api\/drawers\/(\d+)$/` with `req.method === 'DELETE'`
   - `/^\/api\/drawers\/(\d+)\/tools\/(\d+)$/` with `req.method === 'DELETE'`

   Return `{ success: true }` at 200 on success and 404 when nothing matched. The
   codebase returns JSON bodies everywhere, so prefer that over a bare 204.
   Call `writeRequestLog` in both branches.

3. **Dashboard** — a delete control per drawer and per tool in the Toolbox Inventory
   panel, each behind a `confirm()`. Match the existing inline style.

### Gotchas

- **Cascade is wider than it looks.** `drawer_observations` also has
  `ON DELETE CASCADE` on `drawer_id`, so deleting a drawer destroys its observation
  history, not just its tools. Say so in the confirm dialog — include the tool count.
- Place the `/^\/api\/drawers\/(\d+)$/` match **after** the existing
  `/api/drawers` exact-string checks so it cannot shadow them.

### Done when

- Deleting a drawer removes it and its tools; deleting a tool leaves the drawer.
- Deleting a nonexistent id returns 404, not 500.
- Both actions appear in Recent Requests.
- Spec: add both routes to the HTTP Endpoints table in the API Endpoints section.

---

## Feature 4 — Dashboard search

### Why

There is no search box. The page's own copy at `api/public/index.html:410` says
*"Use the API to search by tool name"* — it is telling the user to go run curl.

### The important caveat

`GET /api/tools/lookup` is an **exact match**, not a substring search:

```sql
WHERE name = ?1 COLLATE NOCASE
```

(`selectCanonicalToolName`, `api/src/db.ts:210`.) Typing "phillips" will **not** find
"Phillips Screwdriver #2". Wiring a search box straight to that endpoint produces a
search that mostly returns nothing.

So this feature is client-side:

**Implement:** filter in the browser over the data the dashboard already has.
`GET /api/drawers` returns every drawer with its full `tools` array, which the page
fetches on load anyway. For a box with 8 drawers this is instant, needs no backend
work, no debounce, and no new endpoint. Filter on tool name and drawer label, and show
the matching drawer's `label` and `rowNumber`.

**Do not** add substring matching to `/api/tools/lookup` as part of this feature — see
below.

### Follow-on, tracked separately: fuzzy lookup

Exact matching is a real problem for the **voice** path, not the dashboard. Whisper
will transcribe "phillips screwdriver" and the database holds "Phillips Screwdriver
#2"; an exact match fails and the toolbox says "not found" for a tool it owns. That
needs `LIKE`/token matching plus a confidence notion in `findToolLocations`, and it
changes the firmware-facing contract.

Keep it out of this feature. Add it to the spec's Planned work so it is not lost — it
should be built alongside Feature 2 of the spec (voice), where it actually matters.

### Steps

1. Add a search input to the Toolbox Inventory panel, matching the existing markup and
   glassmorphism styling.
   **Since 2026-10-04 that panel shows one toolbox at a time**, picked from a dropdown in
   its title. Decide whether a search covers only that box or every box - a tool in
   another box is exactly the one a user cannot find by browsing.
2. Filter the already-fetched drawer list on each keystroke; render matches with drawer
   label, row number, and quantity.
3. Empty query → show everything, the current behavior.
4. No matches → an explicit empty state, not a blank panel.

### Done when

- Typing a partial tool name narrows the list live.
- Clearing the box restores the full list.
- Spec: note the search behavior under Dashboard, and add fuzzy server-side lookup to
  Planned Endpoints with the voice-path rationale.

---

## Not in scope for any of these

Recorded so they are not accidentally pulled in:

- `GET /api/tools/find` and `POST /query` are documented as deprecated in the spec but
  still exist in `index.ts`. Nothing calls either — the dashboard does not, and the
  firmware uses the serial channel. Removing them is a separate cleanup.
- Per-instance tool tracking (`tool_id`, checkout state). The project deliberately
  tracks tools by type and quantity; see Tool Identity in the spec.
- Anything needing the microphone, the SenseCraft model, the I2C hub, or the PIR
  sensor. All four are blocked on hardware — see the Hardware Bring-Up Status table.

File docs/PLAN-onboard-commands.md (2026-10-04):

---
title: Plan of Attack - On-board recognition (the box hears the common ones itself)
scope: implementation plan, written 2026-08-31, revised 2026-09-02 after a source
  review of the pinned core - ESP-SR wake word and a local tool vocabulary carried
  from the Pi, with today's Whisper path as the fallback
status: PHASE 2 PROVEN ON HARDWARE 2026-10-04. A person said "Hi ESP" at the box; it
  recorded its four-second window, Whisper heard "screwdriver" and the lookup resolved.
  That also answers the microphone question Phase 1 was skipped over - the mic is good
  enough for WakeNet, thin signal and all. The log does not separately show a second
  wake in a row, so the re-arm line below is accepted on the person's word, not the log.
  Phase 3 is untouched. Everything ships in 0.28.0 behind a partition change, so it
  arrives over USB or not at all. The 2026-09-02 review against esp32-hal-sr.c corrected
  three claims that were wrong in the first draft; they are marked
  **Corrected 2026-09-02** where they appear.
---

# Plan: the box hears the common tools itself, and only asks Whisper when it is unsure

One sentence of scope:

> Say a wake phrase instead of holding the pad, and a tool the box already knows is
> answered without a Whisper round trip - roughly ten seconds saved - with today's path
> still there for everything else.

## Context, so the plan is honest about where it starts

| Piece | State today |
|---|---|
| Hold-to-talk, `voice/audio`, Whisper | **Works end to end** since 0.22.0 |
| PDM mic, 16 kHz 16-bit mono via `ESP_I2S` | **Works.** This is exactly the format ESP-SR wants - see `mic.begin` in the sketch |
| ESP-SR, prebuilt for the S3 | **Already in the pinned core** (3.3.11), as the `ESP_SR` library plus a prebuilt esp-sr archive. Never compiled into this sketch |
| Speech models (`srmodels.bin`, 3,340,296 bytes) | **Ship with the core.** There is nowhere on the device to put them |
| English MultiNet | **Present.** `CONFIG_SR_MN_EN_MULTINET7_QUANT=y` in the pinned sdkconfig. Worth stating: had it been `SR_MN_EN_NONE`, Phase 3 would be impossible and the wrapper compiles the whole command path out |
| Partition table | `default_8MB`. No `model` partition, and no room for one without redrawing the map |
| Wake word | **Not built.** The spec says out of scope and `PLAN-voice-lookup.md` calls it a separate project. This plan is that project |
| Tool catalogue | 1 tool across 5 drawers in the dev database. Designed here for 400 anyway - see Decision 4 |

## What this buys, stated as a number

Whisper is the slow part and always has been: ~9.3s warm against the NAS, over 30s on the
first call after the container has idled. Both numbers are measured, and they are why
`TRANSCRIBE_TIMEOUT_MS` is 90 seconds.

On-device recognition answers in the time it takes to stop talking.

**The Pi round trip does not go away, and should not be described as if it does.** The
drawer mapping lives in SQLite and the device holds no copy, so a local recognition still
calls `tools/lookup` for the drawer. That call is milliseconds. What is skipped is the
transcription, which is the entire ten seconds.

---

## Is the ten seconds ours to fix, or the NAS's

**Settle this before Phase 1, because it is cheap and it changes the value of everything
below.** This plan spends a partition change that cannot be undone over OTA in order to
remove ~9.3s. That is only a good trade if the 9.3s is irreducible, and nothing measured
so far says it is.

Two specific suspicions, both testable in an afternoon and neither requiring hardware:

- **The >30s first call is container idle, not inference.** A periodic no-op request that
  keeps the Whisper container warm removes that number outright, and it is the number a
  person actually notices - the first lookup of the morning is exactly when the box gets
  judged.
- **9.3s warm for a ~2 second clip is slow for what it is.** It is worth reading what
  model and backend the NAS is actually running. `faster-whisper` on CTranslate2 with
  `base.en` and `beam_size=1` typically returns a clip that short in well under two
  seconds on a NAS CPU.

If those two together take ten seconds to two, the case for Phases 2 and 3 is much
weaker, and the honest answer might be "keep the pad, fix the NAS." **Phase 1 is still
worth doing either way** - the wake word is a separate benefit from the latency, and the
microphone question has to be answered before anyone can plan around it.

Whatever the measurement says, record the number here. Every other claim in this document
carries one.

---

## Decision 1: the wake word is "Hi ESP", and that is a choice about esp-sr, not about the problem

The prebuilt libraries compile exactly one wake word: `CONFIG_SR_WN_WN9_HIESP=y`. The
sdkconfig lists Jarvis, Computer, Alexa, Sophia, Mycroft and a dozen more, every one of
them `is not set`. Enabling a different one means rebuilding `esp32-arduino-libs`; a
phrase of our own - "Smart Toolbox" - means commissioning Espressif to train a model.

Both are out of proportion to the feature. **"Hi ESP" is what esp-sr has on offer.**

**The qualifier matters, and the first draft of this document did not have it.** The
constraint belongs to esp-sr, not to the ESP32-S3. **microWakeWord** - the engine ESPHome
ships - runs TFLite-Micro on this chip, its models are around 100 KB, and custom phrases
are trained with their own Colab notebook plus `piper-sample-generator`. "Smart Toolbox"
is an afternoon there, not a commission.

The catch is that microWakeWord is wake-word-only. It has no MultiNet equivalent, so it
would replace Phase 2 and leave Phase 3 to be built on esp-sr anyway or dropped in favour
of always going to Whisper. That is a real fork, not a free upgrade, and it is the reason
the recommendation here is still esp-sr.

Recorded because it decides whether Phase 2 is worth doing at all, and because the
question will be asked again in six months - at which point "Hi ESP is what is on offer"
would have been quoted back as though no alternative existed.

**Phase 3 does not depend on this.** If "Hi ESP" is unacceptable to live with, keep the
touch pad as the trigger and take the local vocabulary anyway. The ten seconds is in the
transcription, not in the pad.

## Decision 2: the vocabulary comes from the Pi at boot, not from the build

Commands are registered at runtime from plain English strings. `esp32-hal-sr.c` runs
`flite_g2p()` on each phrase on the device, hands the result to
`esp_mn_commands_phoneme_add`, then loads the set with `esp_mn_commands_update()`. The
strings are copied out during `begin()`, so anything we pass can be freed straight after.

So the device asks the Pi for the tool list on boot and registers what comes back. The Pi
keeps owning the vocabulary, exactly as it owns the database, the provider config and the
API key.

**Where the phrases actually live, since it is easy to get this wrong:**

- **On the Pi, permanently** - and no new storage is needed for them. The vocabulary *is*
  the `name` column of the `tools` table. It is already there. The endpoint added in
  Phase 3 is a `SELECT`, not a store.
- **On the XIAO, only in RAM, only while powered.** MultiNet holds the phoneme set in
  memory. Nothing is written to the device's flash, and there is no vocabulary on it to
  go stale - a cold boot has no tool names at all until the Pi supplies them.

That asymmetry is the point: **add a tool in the dashboard, reboot the box, it is
recognised. No firmware release.**

The alternative - baking the list into the sketch as a `const sr_cmd_t[]`, the way the
stock example does - was rejected on that sentence alone. It would make every tool
addition a firmware release, and this project already ships firmware often enough to have
built a USB recovery path for it.

### Register incrementally, and do not build the array at all

The obvious reading of the above - fetch the whole list, build one `sr_cmd_t[400]`, hand
it to `begin()` - is the wrong one, and it is worth saying why before somebody writes it.

`esp_mn_commands_add`, `_phoneme_add`, `_remove`, `_clear` and `_update` are all linked
and all callable from the sketch. Both headers are already on every sketch's include path
in this core - `esp-sr/include/esp32s3` and `esp-sr/src/include` are both in
`flags/includes`, so including `esp_mn_speech_commands.h` needs no path hack. The wrapper
does not expose them, but nothing stops us using them directly:

1. Start SR with no commands at all at boot. The wake word works immediately.
2. Fetch the vocabulary a page at a time - 50 names to a response.
3. `esp_mn_commands_add(id, name)` per name as each page lands.
4. One `esp_mn_commands_update()` at the end.

**What that avoids, in order of how much it matters:**

- **The device is never deaf because the Pi is down.** Registering through `begin()` means
  no vocabulary implies no `begin()` implies no wake word at all. Deaf, not degraded, and
  for a box whose entire job is answering questions that is the worst failure mode
  available. Starting SR before the vocabulary arrives is not an optimisation, it is the
  difference between degrading and dying.
- **The 104 KB command array stops existing.** `sr_cmd_t` is 260 bytes and
  `SR_CMD_STR_LEN_MAX` is 256 - a fifth of internal SRAM to hold strings that are mostly
  padding, on a chip that will also be hosting AFE and MultiNet buffers.
- **The 12 KB JSON line stops existing.** `handleIncomingLine` builds `serialLineBuffer` a
  character at a time into an Arduino `String` on the internal heap, then hands it to a
  `JsonDocument` on the same heap. At 12 KB that is quadratic reallocation, fragmentation,
  and plausibly 30-40 KB of internal SRAM live at once - at exactly the moment SR is
  trying to allocate. 50 names a page is a line the existing transport already handles.
- **`loop()` keeps running between pages.** Heartbeats to the Pi, the OLED, the matrix.
  A single blocking registration of the whole catalogue stops all three for however long
  400 `flite_g2p()` calls take, which is still unmeasured.

### Version the vocabulary, and cache the phonemes against that version

Return a hash of the list alongside it, and store hash plus phonemes in `nvs`. Two things
fall out for almost no work:

- **`flite_g2p` becomes a first-boot cost rather than an every-boot one.** Feed the cached
  phonemes to `esp_mn_commands_phoneme_add` and skip g2p entirely.
- **"Reboot the box" becomes "next heartbeat".** The device already asks the Pi something
  every 30 seconds. Comparing one hash is cheap enough to do there, and re-syncing a
  running model is what the add, remove and update calls are for.

Neither is required for Phase 3 to work. Both are cheap enough that designing the endpoint
without a version field would be the mistake.

## Decision 3: local first, Whisper on anything short of certain - but the fallback is not free

**Corrected 2026-09-02.** The first draft of this section described a fallback that cost
nothing and lost nothing. Both halves were wrong, and the correction changes the design
rather than just the wording.

### What the first draft said, and why it does not hold

The claim was: set `set_det_threshold` high, and anything the model is not sure about
surfaces as `ESP_MN_STATE_TIMEOUT`, which becomes the Whisper trigger - so **"the worst
case is today's behaviour."**

Two problems, both in the core's source:

- **`set_det_threshold` cannot be reached.** It is a function pointer on `esp_mn_iface_t`
  and needs the `model_data` handle. Both live inside the file-static `g_sr_data` in
  `esp32-hal-sr.c`, and there is no getter. Calling `sr_start()` directly does not help -
  it creates the model internally too. The knob the plan was built around does not exist
  at the sketch level.
- **The timeout is a clock, not a confidence signal.** `esp32-hal-sr.c` creates MultiNet
  with a duration argument of 5760. That is the detection window in milliseconds.
  `ESP_MN_STATE_TIMEOUT` does not mean "unsure", it means **5.76 seconds have elapsed
  since the wake word**. By the time it fires the person has long finished speaking, and
  the audio they spoke is gone.

So the real worst case was: today's round trip, **plus** ~5.8 seconds of dead air,
**plus** the box asking them to say it again. That is not today's behaviour, it is
noticeably worse than the touch pad, and it would have been discovered on hardware rather
than on paper.

### What to build instead: tee the audio on its way past

`sr_start()` is declared in the public `esp32-hal-sr.h` and takes a fill callback. The
wrapper's own callback does nothing but read the `I2SClass`. So skip `ESP_SR.begin()`,
call `sr_start()` with our own fill callback, and have it copy each chunk into a PSRAM
ring buffer on its way to the AFE.

Then on `SR_EVENT_TIMEOUT` the last few seconds of audio are already in hand and go
straight to `voice/audio`. **The person says the tool name once.** The fallback costs the
detection window and nothing else, and the original claim - that a miss costs roughly what
was already being paid - becomes true rather than aspirational.

It also removes the I2S race outright: with the tee there is exactly one reader of that
peripheral, forever. See Gotchas.

### The threshold, if it is still wanted

Two ways to get one, and the choice belongs in Phase 1 rather than Phase 3 because it
decides what Phase 3 is:

- **Per-phrase.** `esp_mn_phrase_t` carries a `float threshold`, default 0. Reachable
  through the command list without touching `model_data`.
- **Vendor `esp32-hal-sr.c` into the sketch.** It is Unlicense or CC0, which is the same
  reason the Grove matrix driver is vendored here with a `docs/SOURCES.md` entry. That
  single move buys the model-level threshold, the re-arm fix, the tee, and access to the
  five candidates below - all in one file we control.

### What is given up on a local hit

The underlying result carries up to five candidates with probabilities
(`ESP_MN_RESULT_MAX_NUM`), but the Arduino callback collapses them to one `command_id`.
`matchBestOverlap` deliberately returns every screwdriver and lights every row; a local hit
through the wrapper cannot do that. Letting ambiguity fall through to Whisper, where
`resolveToolQuery` already handles it properly, is still the right default. Vendoring the
hal is the way to stop giving the candidates up, if it turns out to matter.

## Decision 4: 400 is a ceiling on phrases, and the Pi enforces it

`ESP_MN_MAX_PHRASE_NUM` is 400, compiled into the prebuilt archive. Editing the header
does nothing.

**It counts phrases, not tools.** Multiple phrases can share a `command_id`, which is how
"needle nose pliers" and "needle-nose pliers" would both reach one drawer. At 400 tools
that budget is exactly one phrasing each.

So the device takes a list of N and registers it, and **the Pi decides what N is and what
is in it.** Sixty tools or four hundred is the same firmware. If the list ever comes back
over budget the Pi truncates it, ranked, and logs what it dropped - the box degrades
honestly instead of half-registering in silence.

**The Pi should enforce the length limits too, not just the count.**
`ESP_MN_MAX_PHRASE_LEN` is 63 characters and `ESP_MN_MIN_PHRASE_LEN` is 2. Note that
`sr_cmd_t.str` is 256 bytes, so nothing rejects an over-long name until deep inside
`esp_mn_commands_update()`. Checking on the Pi means a bad tool name is visible in the
dashboard next to the tool, rather than inferred from an error list that came back over
serial.

**Storage does not raise the 400 and should not be proposed as a fix.** 400 tool names is
about 12 KB of text; the existing 20 KB `nvs` partition would hold them several times
over. The limit is in the recogniser's search graph. An SD card - and the Sense board has
a slot, and `CONFIG_MODEL_IN_SDCARD` is real in esp-sr, though off in the prebuilt libs -
would only relocate the 3.2 MB model blob off flash. It adds no vocabulary.

The honest reason not to want more than 400 is accuracy, not memory. Closed-set
recognition gets worse as the set grows and tool names crowd together phonetically
("half inch socket" against "half inch wrench"). Decision 3 is what keeps that from being
a user-visible failure.

---

## The partition change

The device's flash is not a folder. It is a fixed map of regions, set at flash time, and
every byte belongs to a region whether anything is in it or not. **Old builds do not
accumulate there** - there are exactly two app slots, permanently, and OTA alternates
between them.

So "full" means over-allocated, not cluttered:

| Region | Reserved | In use |
|---|---|---|
| `app0` | 3,342,336 | 1,091,984 |
| `app1` | 3,342,336 | 1,091,984 |
| `spiffs` | 1,572,864 | nothing - no filesystem code in the sketch |

Roughly 5.8 MB reserved and idle. Redrawing it:

```
# Name,   Type, SubType, Offset,   Size,     Note
nvs,      data, nvs,     0x9000,   0x5000
otadata,  data, ota,     0xe000,   0x2000
app0,     app,  ota_0,   0x10000,  0x250000  # 2,424,832 - 2.2x the current binary
app1,     app,  ota_1,   0x260000, 0x250000
model,    data, spiffs,  0x4B0000, 0x340000  # 3,407,872 - the blob is 3,340,296
coredump, data, coredump,0x7F0000, 0x10000
```

Ends on 0x800000 exactly. `spiffs` is gone because nothing uses it. **OTA survives** -
both slots are still there, right-sized. The partition must be labelled exactly `model`:
`sr_start()` calls `esp_srmodel_init("model")` and nothing else will be looked at.

**The app/model split is the knob, and it is worth turning deliberately.** The first draft
gave the model 0x3E0000, which is 706 KB more than the blob needs, and took it out of the
app slots. The table above leaves the model 66 KB of headroom instead and hands the rest
to the application. If a future core bump grows `srmodels.bin`, 0x240000 app slots against
a 0x360000 model is the same table with the balance moved back.

**Measure before choosing.** Linking `ESP_SR` pulls in `libdl_lib.a`,
`libespressif__esp-tflite-micro.a`, `libespressif__esp-nn.a` and `libflite_g2p.a`. The
current binary is 1,091,984 bytes and that number is about to grow by an amount nobody
here has measured. Phase 1 produces it. **Pick the slot size from the measurement, not
from this table**, because getting it wrong costs a trip to the box with a cable.

Four things this forces:

1. **It cannot ship over OTA.** A partition table change is not an application update.
   This is one `flash-device.ps1` run at the box. Every `esp_sr_*` scheme in the core is
   16 MB-only, so the partition file is ours, not the core's - a `partitions.csv` in the
   sketch folder is picked up by the core's prebuild hook and overrides the board's
   scheme.
2. **The merged image carries the table but not the model, and that is a trap.**
   **Corrected 2026-09-02.** Good news first: the merge recipe writes the partition table
   at 0x8000, so `flash-device.ps1` already delivers the new map, and the first draft's
   "plus a separate esptool write of the table" was unnecessary. The bad news is worse
   than the good news is good. The recipe is hardcoded to bootloader, partitions,
   `boot_app0` and the app - **the model blob is not in it** - and it pads to the full
   8 MB. `flash-device.sh` writes that at 0x0. So **every USB recovery flash zeroes the
   model partition**, and the device comes back with recognition silently broken. The path
   this whole plan leans on destroys the feature's data every time it runs.
   The fix belongs in `release-firmware.ps1`: re-run the esptool merge with
   `0x4B0000 srmodels.bin` added. The core already drops `srmodels.bin` into the build
   directory whenever `ESP_SR` is linked, so the file is sitting there. Recovery stays one
   command and the image stays 8 MB.
3. **Every existing merged image becomes a hazard.** Everything in `api/firmware/` from
   0.10.0 onward carries the `default_8MB` table. Flashing one after this change restores
   the old map and destroys the model partition, and `flash-device.sh` only guards on file
   size so nothing stops it. This is why the pruning note at the bottom of this document
   stops being housekeeping - at minimum the flash script needs a version floor.
4. **`upload.maximum_size` will lie.** The XIAO's `default_8MB` menu entry sets it to
   3,342,336 in `boards.txt`, and a sketch-folder `partitions.csv` does not change it.
   `arduino-cli` will happily build a 2.5 MB binary for a 2.3 MB slot and say nothing at
   all. `release-firmware.ps1` needs its own size check against the real slot.

**It is exactly the kind of change `PLAN-usb-flashing.md` was built for.** Get the table
wrong and the device does not boot. The ROM bootloader is the way back, and it has been
proven on a deliberately bricked device.

One cosmetic note so nobody chases it: `esp32-hal-sr.c` opens with a `#warning` that a
compatible partition must be selected, keyed on the core's own `esp_sr_8/16/32` scheme
names. Our `build.partitions` stays `default_8MB` whatever the sketch `partitions.csv`
says, so the warning fires on every build and means nothing.

---

## Phases

**Phase 1 answers the question the rest of the plan depends on.** Do not build Phase 2
until it has passed - if this microphone will not drive WakeNet in this workshop, nothing
downstream matters, and the cheapest way to find out is a throwaway sketch.

## Phase 1 - does this microphone work with ESP-SR at all

> **Skipped 2026-09-06.** Phase 2 was built without it, on the instruction to hook the
> wake word up to search mode. The risk this phase existed to retire is therefore still
> live: **nobody knows whether this microphone drives WakeNet.** What that changes in
> practice is where the answer comes from - the first person to stand at the box and say
> "Hi ESP" is now running Phase 1, without the throwaway sketch that would have isolated
> it. If it does not fire, the recording path is not the suspect. Gain and DC-offset
> correction on the mic feed are, and they are Step 1 of `docs/PLAN-mic-bringup.md`.
>
> **The binary size this phase was meant to produce was measured anyway**, by compiling
> the real firmware rather than the example, and the partition table is sized from it
> instead of from the estimate this document originally carried:
>
> | Build | Bytes |
> |---|---|
> | 0.27.0, no `ESP_SR` | 1,096,267 |
> | 0.28.0, `ESP_SR` linked | 2,189,531 |
> | app slot in `firmware/smarttoolbox/partitions.csv` | 2,424,832 |
> | headroom | 235,301 (90.3% full) |
>
> Static RAM went from 50,340 to 62,868 bytes, and that is before the SR tasks allocate
> at runtime. **The estimate in "The partition change" below was right**, which is worth
> recording because it was arithmetic rather than luck: the model needs 3.34 MB and the
> two app slots and the model share 8,257,536 bytes, so there was never a second option.
>
> One trap found while doing it, and it is the reason the release script now checks:
> **arduino-cli reports the wrong maximum.** It takes the "Maximum is ..." figure from
> the board definition, not from `partitions.csv`, so it called this binary 65% of
> 3,342,336 when it is 90.3% of 2,424,832. A build that overflows the real slot compiles
> clean and fails at the box. `release-firmware.ps1` now reads the app slot size out of
> the partition table itself and refuses the release.

### Design

Repartition, flash the stock `ESP_SR` `Basic` example with the PDM pins changed to 42/41
and mono input, and stand in the workshop saying "Hi ESP".

Nothing from this phase ships. It exists to retire one risk: the spec records this audio
sitting at **4-10% of full scale, with no gain applied and the DC offset not stripped**.
Whisper tolerates that. WakeNet is fussier, and a wake word that needs shouting is worse
than the touch pad it replaces.

### Steps

1. Write `firmware/smarttoolbox/partitions.csv` with the table above. Arduino picks up a
   `partitions.csv` from the sketch folder.
2. Flash it over USB, plus `srmodels.bin` at 0x4B0000. Confirm the device still boots and
   the existing firmware still runs from a 2.3 MB slot.
3. Flash the modified `Basic` example. **Mono needs two settings, not one:** the input
   format string `"M"` *and* `SR_CHANNELS_MONO` passed to `begin()`. The default channel
   argument is stereo, which gives an I2S channel count of 2 against a feed channel count
   of 1, and the assertion in `sr_start` aborts the boot. Presents as "the device will not
   start", which is a long way from its cause.
4. Watch the serial log for the wake event.
5. Say it twenty times from where a person actually stands. Count the misses.
6. Then say a few of the example's command phrases and count those.
7. **Record the compiled binary size with `ESP_SR` linked.** One number, written into this
   document, and the app slot sizing stops being guesswork.

### Done when

- A number exists for how often "Hi ESP" fires from normal speaking distance.
- A number exists for command recognition on the same mic.
- A number exists for the ESP-SR-linked binary size, and the partition table above has
  been confirmed or adjusted against it.
- If either recognition number is bad, this plan stops here and says so in its `status:` -
  with the numbers, so the next person does not repeat it. Gain and DC-offset correction
  on the mic feed would then be the prerequisite, not a tweak.

---

## Phase 2 - the wake word in the real firmware

### Design

`ESP_SR` replaces the touch pad as the trigger. The pad stays wired and working: it is
the thing that still functions when recognition does not, and it costs nothing to keep.

### Steps

1. Start SR in `setup()`, **before** the Pi readiness handshake rather than after - see
   Decision 2 on why waiting makes the box deaf rather than degraded when the Pi is down.
2. On `SR_EVENT_WAKEWORD`, run the recording path that the touch pad runs today. Mono does
   not raise `SR_EVENT_WAKEWORD_CHANNEL`, so the mode switch has to happen in the
   `SR_EVENT_WAKEWORD` branch.
3. **Re-arm after every event.** See Gotchas - this is the one that will look like a
   hardware fault.
4. Handle the I2S conflict - see Gotchas.
5. Show the wake state on the OLED and the matrix. A box that is listening should look
   like it, or the first failure is indistinguishable from the second.

### Done when

**Met 2026-10-04** - see the status above for what the log does and does not show.

- Saying "Hi ESP" starts a recording that reaches Whisper and lights a row.
- Saying it **twice in a row** works twice. That is the re-arm bug, and it earns its own
  line in the acceptance criteria because the first time is not the test.
- The touch pad still does the same thing.
- Firmware version bumped, released, and the spec's Feature 2 wake-word scope corrected.

---

## Phase 3 - the local vocabulary, and the fallback

### Design

The Pi gains a paged endpoint that returns the tool vocabulary and a version hash. The
device pages it in during the readiness wait it already sits through - the Pi takes 36.6s
to come up, and 400 `flite_g2p()` calls have to happen somewhere. It registers
incrementally as pages arrive, rather than building one array and handing it to
`begin()` - see Decision 2 for why.

Registration failures are reported, not swallowed: `esp_mn_commands_update()` returns an
error struct listing every phrase that could not be added, which is how a tool name full
of digits and fractions announces itself instead of going quietly deaf.

### Steps

1. Pi side: an endpoint returning a page of tool names plus a version hash, ranked, and
   truncated with a log line when the catalogue exceeds the budget. Reject names outside
   2-63 characters here, where the dashboard can show it.
2. Device side: page in the vocabulary during the readiness wait, `esp_mn_commands_add`
   per name, one `esp_mn_commands_update()` at the end. No command array.
3. Cache phonemes in `nvs` against the version hash, so g2p is a first-boot cost.
4. Report the registration failures back to the Pi so they land in the request log. A tool
   the box structurally cannot hear is worth seeing in the dashboard.
5. Wire the fallback: the tee'd ring buffer from Decision 3, shipped to `voice/audio` on
   `SR_EVENT_TIMEOUT`.
6. Log which path answered - local or Whisper - on every lookup. Without that line there
   is no way to tell a working feature from one that silently falls back every time.

### Done when

- Say "Hi ESP", then a tool the Pi sent, and the matrix lights the row **with no
  transcription in the log**.
- Say a tool it does not know, and the log shows the fallback firing and Whisper answering
  **without the person repeating themselves**.
- Add a tool in the dashboard, reboot, and it is recognised without a reflash.
- Unplug the Pi, reboot the box, and "Hi ESP" still wakes it - it just cannot answer.

---

## Gotchas

- **SR must be re-armed after every command and every timeout.** `esp32-hal-sr.c` sets the
  mode to off on both a detection and a timeout. Without an explicit return to
  `SR_MODE_WAKEWORD` in the event handler, **the box works exactly once and is then
  deaf** - which is the failure that looks identical to a dead microphone, a wrong
  threshold and a frozen peripheral, and is exactly what the Debugging section of the spec
  exists to separate. The stock `Basic` example shows the pattern; it is easy to read past
  because the interesting-looking lines are the command switch.
- **`pause()` is not synchronous.** It sets event group bits. The feed task may already be
  parked inside the fill callback on a blocking `readBytes`, so after `pause()` returns
  that task can still consume the next chunk - racing `recordWhileHeld` on the same
  `I2SClass`. Teeing the audio (Decision 3) makes this moot by having exactly one reader
  of the peripheral. If the tee is not built, the pause has to be drained rather than
  trusted.
- **The OTA check blocks the loop for up to 25 seconds** when the radio cannot associate,
  and SR has to keep detecting through that. **Corrected 2026-09-02:** it does, but not
  for the reason the first draft gave. The tasks are not all pinned to core 0. Feed is on
  core 0; **detect and handler are both on core 1**, at priority 5, 5 and near-maximum
  against `loop()` at priority 1 on that same core 1. Detection survives a blocked `loop()`
  by preempting it, not by living on another core - so the conclusion held and the reason
  did not, which is worth knowing before anyone reasons from it again.
  The real hazard is different and worth watching instead: MultiNet7 defaults to loading
  part of its weights from flash rather than PSRAM, so weights are read **from flash
  during detection**, and `Update.write()` stalls the flash cache. Recognition during an
  OTA write is the thing to test, not core contention.
- **`flite_g2p` runs once per phrase, and it runs on the calling task.** With the
  incremental registration in Decision 2 that cost is spread across pages and `loop()`
  keeps running. Doing it the other way - all 400 inside one `begin()` - stops heartbeats,
  the OLED and the matrix for an unmeasured duration. The task watchdog is set to 5
  seconds with panic enabled, but `loopTask` is not subscribed in this sdkconfig, so a
  long registration stalls rather than panics. Small mercy, easy to mistake for a hang.
- **Digits and fractions are the likely failures.** "3/8 socket", "1/2 inch wrench" -
  flite's letter-to-sound rules were not written for those. They fail at registration,
  visibly, which is the good case.
- **`ESP_MN_MAX_PHRASE_LEN` is 63 characters**, `ESP_MN_MIN_PHRASE_LEN` is 2, and
  `sr_cmd_t.str` is 256 - so nothing rejects an over-long name until deep inside
  `esp_mn_commands_update()`. Validate on the Pi.
- **Recognising a tool with the Pi down gets you nothing.** The drawer mapping is in
  SQLite. Do not be tempted into caching it on the device to make the box work offline;
  that is a second copy of the database to keep in sync.

## Open questions to settle before starting

1. **Is the ten seconds ours to fix at all?** A warm container and a faster Whisper backend
   may take 9.3s to under 2s for an afternoon's work and no partition change. See the
   section above. Measure this first - it is the only open question that can make the rest
   unnecessary.
2. **Does this microphone drive WakeNet at 4-10% of full scale?** Phase 1 exists to answer
   it. Everything downstream is contingent.
3. Is "Hi ESP" acceptable to live with? If not, Decision 1 says the plan still works with
   the pad as the trigger, and microWakeWord is the fork worth costing before Phase 2
   rather than after.
   **Answered 2026-10-04: yes, for now.** A switch to "Computer" was looked at and is
   smaller than Decision 1 assumes - the wake word is one 291 KB model inside
   `srmodels.bin`, and esp-sr 2.4.6 (the version the pinned core links) ships
   `wn9_computer_tts`, so it is a repack of the model blob rather than a rebuild of
   `esp32-arduino-libs`. Deferred because it was not free: `release-firmware.ps1` would
   need to splice our own blob instead of the core's, and the `_tts` model is trained on
   synthetic speech.
4. **Do we vendor `esp32-hal-sr.c`?** Decision 3 needs an answer before Phase 3 is
   designed, not during it. Vendoring buys the detection threshold, the re-arm, the tee
   and the five candidates in one file we control, at the cost of a file we now maintain.
   The Grove driver is the precedent in both directions.
5. How long do 400 `flite_g2p()` calls take on this chip - and does the `nvs` phoneme
   cache make it a question that only matters once?
6. Does the I2C traffic to the OLED and matrix disturb SR timing? **Probably the wrong way
   round:** the detect task at priority 5 preempts `loop()` at priority 1 on the same core,
   so the thing to watch is SR starving the display - stretched `matrixPush()` and U8g2
   transfers, a wave animation that stutters while the box is listening.
7. Ranking: when the catalogue exceeds the budget, ranked by what? `request_logs.tool`
   holds the raw query or transcript, not the canonical name, so counting it needs either
   a resolve at query time or a `resolved_tool` column. Not needed until a real catalogue
   passes 400 - which, at five drawers, is not soon.

## Done when

- "Hi ESP", a tool name, and the right row lights with no Whisper call.
- An unknown tool falls through to Whisper and is answered correctly, without the person
  repeating themselves.
- A tool added in the dashboard is recognised after a reboot, with no firmware release.
- `bun test` covers the vocabulary endpoint, its paging, and its truncation.
- `release-firmware.ps1` merges the model blob into the merged image, and checks the app
  binary against the real slot size rather than the stale `upload.maximum_size`.
- Spec: the Microphone section records that ESP-SR runs on this mic and at what
  reliability; Feature 2 stops saying a wake word is out of scope and describes the
  hybrid; the Communication Protocol gains the vocabulary endpoint; and the custom
  partition table is documented next to the OTA description, because the next person to
  run `release-firmware.ps1` needs to know the slots are no longer 3 MB.
- `xiao-esp32s3-firmware.instructions.md` gains the I2S-ownership trap, the re-arm trap,
  and a note - in the spirit of the `PSRAM=opi` one - that the models live at 0x4B0000 and
  that a merged image without them silently disables recognition.

---

## Unrelated to the space problem, but no longer unrelated to this plan

Filed here because it came up in the same conversation. **Nothing deleted here frees a
single byte on the device** - but the 2026-09-02 review found that these files stop being
merely large once the partition table changes.

`api/firmware/` holds every release since 0.10.0 - **56 MB**, including 8 MB merged
recovery images - and `release-firmware.ps1 -Push` mirrors it to
`~/smarttoolbox/firmware/` on the Pi, whose storage is an SD card.

`firmware.ts` serves the newest by version, so older builds exist only for rollback.
Keeping the last two or three plus the current merged image is enough. Worth a prune step
in `release-firmware.ps1` rather than a one-off cleanup, so it does not grow back.

**The part that is now load-bearing:** every one of those merged images carries the
`default_8MB` partition table. After the repartition, flashing any of them silently
restores the old map and destroys the model partition, and `flash-device.sh` only checks
file size so nothing stops it. Whatever else the prune does, `flash-device.sh` needs a
version floor before Phase 1 ships - refusing to flash a merged image built before the
repartition is a two-line change, and the alternative is a recovery path that quietly
breaks the thing it was used to recover.

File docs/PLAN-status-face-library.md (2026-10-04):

---
title: Plan of Attack - extract the status face into a reusable library
scope: implementation plan, written 2026-09-02 - lift the matrix state/picture layer
  out of smarttoolbox.ino into a standalone Arduino library, after a survey found
  nothing existing that covers it
status: PLANNED - nothing built. Phase 0 is a pure refactor whose acceptance test is "the
  same pictures with the same timings", so it is safe to start any time. Publishing
  (Phase 4) must not happen until Phase 3 has driven a second, non-Grove display -
  before that the abstraction is a guess, and the library name is permanent.
---

# Plan: a status vocabulary for displays too small for a face

One sentence of scope:

> The pictures the box uses to say what it is doing - idle, thinking, listening,
> booting, an answer, three kinds of failure - become a library another project can
> depend on, without dragging SmartToolbox's drawers, certainty scores or Grove panel
> along with them.

## Context: what the survey found

Searched before designing. Three families of library exist and none of them is this.

**Robot faces.** [FluxGarage RoboEyes](https://github.com/FluxGarage/RoboEyes) draws
animated eyes over Adafruit_GFX with moods (happy, tired, angry, default), an
autoblinker, and tweened transitions. [M5Stack-Avatar](https://github.com/meganetaaan/m5stack-avatar)
does the same on M5Unified hardware with a component tree of eyes, mouth and eyebrows.
Both assume a framebuffer large enough for the eye to be a *shape* - rounded corners, a
border radius, sub-pixel motion. At 8x8 an eye is four pixels and every one of those
techniques is unavailable. Both are also faces only: they have no answer to "now show a
result and go back to idle in four seconds".

**Status LEDs.** [JLed](https://github.com/jandelgado/jled),
[Blinkenlight](https://github.com/tfeldmann/Arduino-Blinkenlight),
[statusLED](https://github.com/TheDIYGuy999/statusLED),
[GFLED](https://github.com/geekfactory/GFLED). These have the right *architecture* -
declarative patterns, an effect state machine, a non-blocking `update()` driven from
loop - and it is worth stealing. They drive a single LED's brightness. One channel.

**8x8 emoji tutorials.** LedControl or MaxMatrix plus a hand-drawn byte array per face.
That is the bitmaps and nothing else: no animation, no timing, no state.

And the Grove driver already vendored here exposes `displayEmoji()` with 30 built-in
glyphs, which this firmware deliberately does not use - the panel applies its
orientation setting to on-device glyphs separately from user frames, so a built-in
emoji and a hand-drawn face would not agree on which way is up (see the `DIGIT_GLYPHS`
comment in `smarttoolbox.ino`).

**Conclusion: build it**, and move *both* halves - the bitmaps and the rules that govern
them.
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

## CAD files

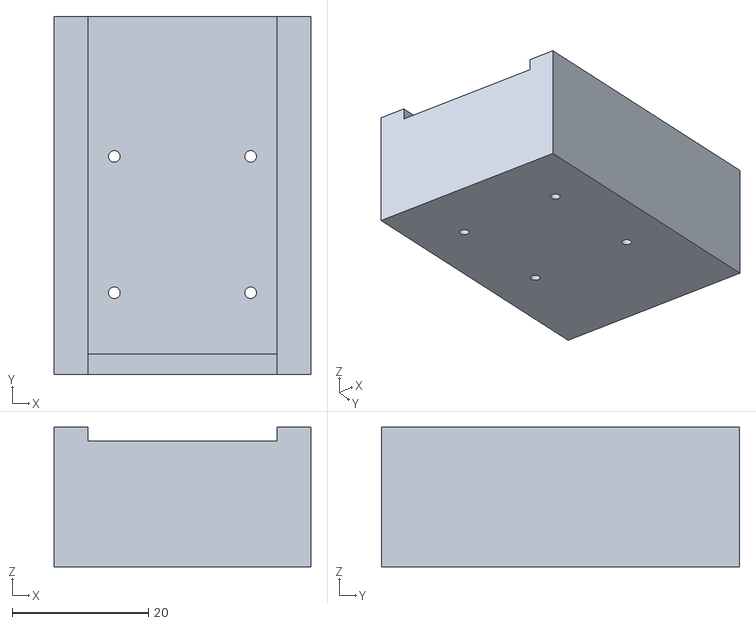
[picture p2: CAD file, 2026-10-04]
cad/vision_cradle.stl
37.7 x 52.5 x 20.5

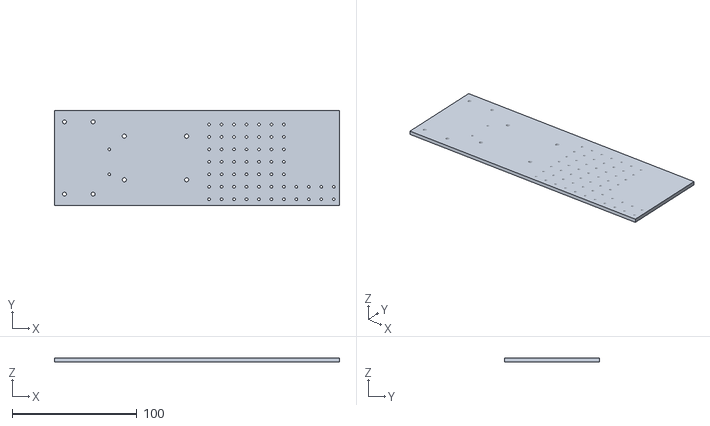
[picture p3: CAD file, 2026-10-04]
cad/mounting_plate_v6.stl
228.6 x 76.2 x 3.00

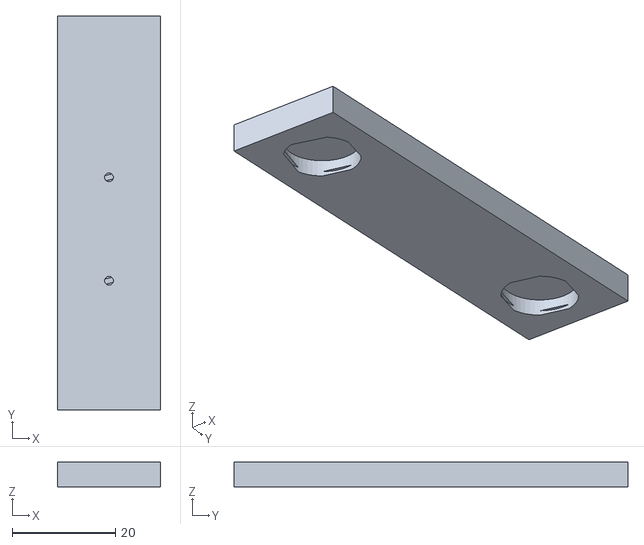
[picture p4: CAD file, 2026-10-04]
cad/magnet_bar.stl
20.0 x 76.2 x 4.80

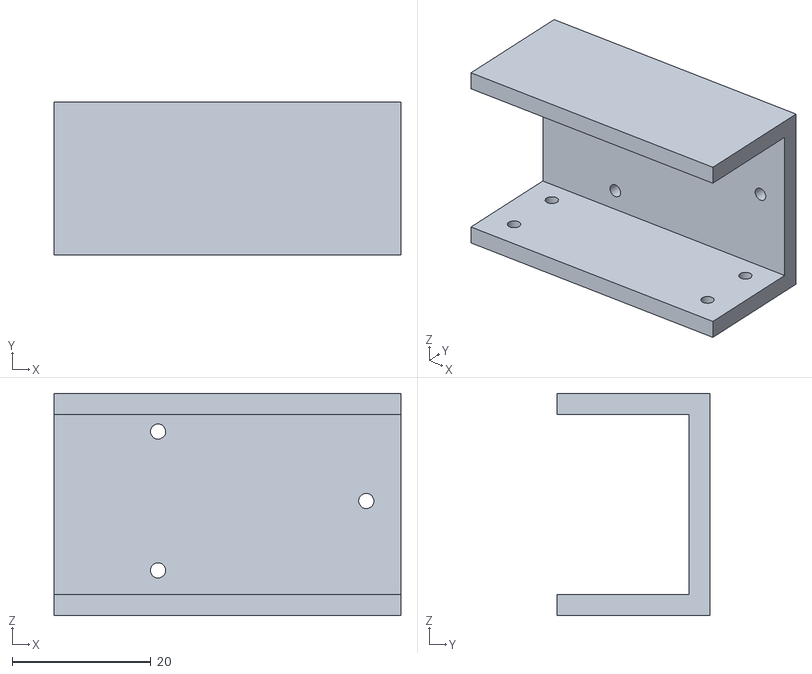
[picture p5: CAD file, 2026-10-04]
cad/pir_bracket.stl
50.0 x 22.0 x 32.0

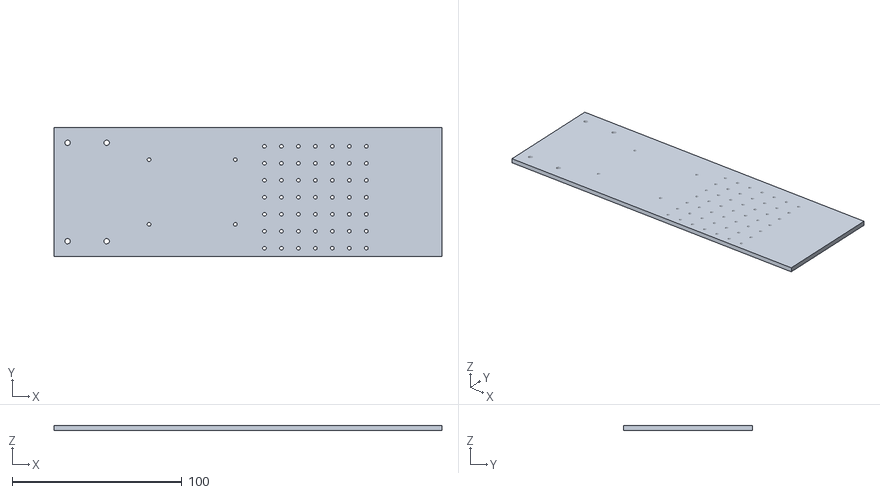
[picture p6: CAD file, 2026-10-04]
cad/mounting_plate_v5.stl
228.6 x 76.2 x 3.00

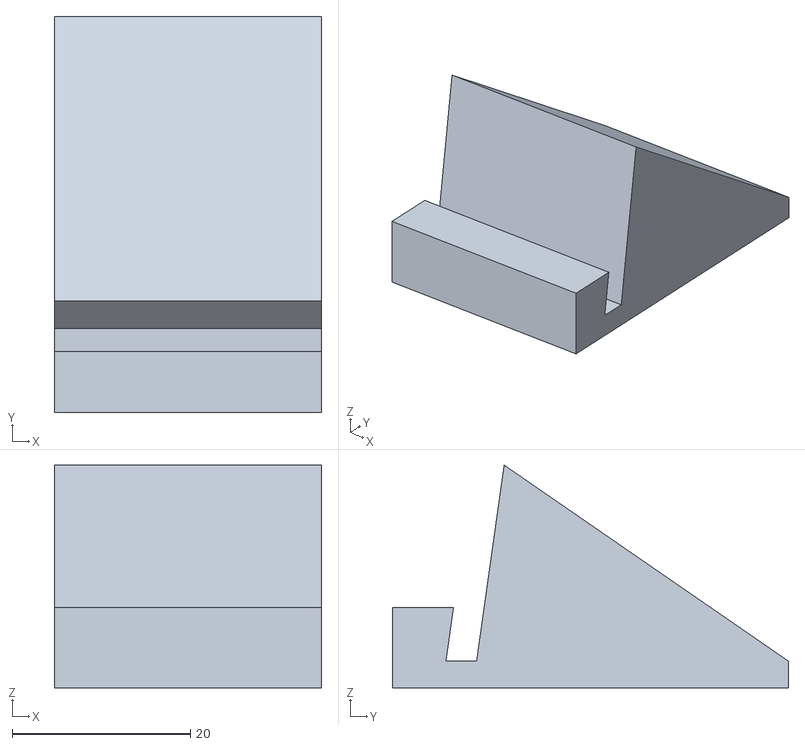
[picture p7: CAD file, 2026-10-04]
cad/foot.stl
30.0 x 44.4 x 25.0

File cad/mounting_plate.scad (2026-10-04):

// SmartToolbox back plate, v6.
// Regenerate the STL from here once OpenSCAD is installed, or run build_plate.py,
// which is what actually produced the shipped mesh. Keep the two in step.
// Y = 0 is the bottom edge: the one the LED strip and the PIR look down from.

plate_w = 228.6; plate_h = 76.2; plate_t = 3.0;
d_m2 = 2.2;          // M2 clearance, the whole component grid
d_pi = 3.2;          // Pi Zero standoffs
d_exp = 3.4;         // the board's own holes are 3.0; this adds print slack

pi_x = [8.0, 31.0];
pi_y = [9.1, 67.1];

exp_x0 = 56.0; exp_y0 = 20.60;   // XIAO Expansion Board Base
exp_dx = 50.0; exp_dy = 35.0;       // hole centres, in a 58.0 x 42.5 board

grid_x = [for (i = [0:6]) 124.0 + 10 * i];   // v4's left 8 columns removed
grid_y = [for (i = [0:6]) 5.0 + 10 * i];
rail_x = [for (i = [0:3]) 194.0 + 10 * i];   // bottom two rows only
rail_y = [5.0, 15.0];
bar_x = [44.0];   // the left magnet bar; the right one reuses column 184
bar_y = [25.0, 45.0];

module holes() {
    for (x = pi_x, y = pi_y) translate([x, y]) circle(d = d_pi, $fn = 48);
    for (dx = [0, exp_dx], dy = [0, exp_dy])
        translate([exp_x0 + dx, exp_y0 + dy]) circle(d = d_exp, $fn = 48);
    for (x = grid_x, y = grid_y) translate([x, y]) circle(d = d_m2, $fn = 48);
    for (x = rail_x, y = rail_y) translate([x, y]) circle(d = d_m2, $fn = 48);
    for (x = bar_x, y = bar_y) translate([x, y]) circle(d = d_m2, $fn = 48);
}

linear_extrude(plate_t) difference() {
    square([plate_w, plate_h]);
    holes();
}

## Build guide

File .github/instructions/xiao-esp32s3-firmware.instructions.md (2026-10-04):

---
name: XIAO ESP32S3 Firmware
applyTo: "firmware/**/*.ino"
description: "Firmware guidance for the Seeed XIAO ESP32S3, including onboard LED polarity, touch GPIOs, upload settings, and hardware constraints."
---

# XIAO ESP32S3 Firmware Guidance

- Target board: `esp32:esp32:XIAO_ESP32S3`.
- The installed ESP32 board definition maps `LED_BUILTIN` to GPIO21.
- The onboard orange/amber charge or power indicator is separate from the programmable orange user LED and is expected to remain on when its power or charging condition is active.
- The XIAO user LED is active-low: use `LOW` to turn it on and `HIGH` to turn it off.
- The Seeed pin map labels D0-D5 and D8-D10 as touch-capable exposed pads: GPIO1-9. GPIO0 is the Boot strapping pin and is not a touch input for this test.
- **GPIO5 (D4) and GPIO6 (D5) are the I2C bus** (`SDA`/`SCL` in the `XIAO_ESP32S3` variant) and carry the Grove OLED. They are touch-capable on paper, but do not map them as touch pads - reading them fights the display. The usable touch pads are GPIO1-4 and GPIO7-9.
- The `RST` and `BOOT` controls are physical buttons, not capacitive touch inputs. Touch sensing requires an exposed touch-capable GPIO pad, such as GPIO1 / D0, or a separately wired capacitive electrode.
- Seeed documents a factory touch-light program for the regular XIAO ESP32-S3: touching an exposed touch pad turns on the orange user indicator.
- Touch thresholds should be calibrated from startup samples instead of relying on a fixed raw value.
- **Touch readings rise when a pad is touched on this chip.** The ESP32-S3 uses touch sensor v2, where the raw value goes *up* on contact - the opposite of the original ESP32, where it falls toward zero. The core's own header is explicit: `touchRead` is documented as "for ESP32 values close to 0 mean touch detected / for ESP32-S2/S3 higher values mean touch detected" (`cores/esp32/esp32-hal-touch.h`). A threshold written as `value < baseline * 0.7` never fires here and presents as touch being silently dead. Compare against `value > baseline * ratio` instead.
- **Discard the first ~10 `touchRead` calls after boot.** They come back roughly 8x high while the peripheral settles. Averaging them into a startup baseline puts the threshold above anything a real touch can reach, which looks identical to a dead pad. Measured on D0: a baseline taken from the first reads landed at 239,519 against a true idle value of ~18,340.
- **Do not read several pads back-to-back with no gap.** Scanning all nine pads in a tight loop made `touchRead` return a frozen constant (2,513,860 on every call, never varying) instead of live data. Scan only the pads you actually use, or space the reads out.
- Reference readings on D0, once calibrated correctly: **~18,300 idle, ~31,400 while touched** - a ~70% rise, so a trigger ratio of 1.15x baseline has wide margin.
- `touchInterruptSetThresholdDirection()` does **not** exist on the S3 - the core guards it with `#if SOC_TOUCH_SENSOR_VERSION == 1`, so it is ESP32-only. There is no direction to flip; the direction is fixed by the silicon.
- **Wi-Fi needs the external antenna.** The XIAO ESP32S3 has no usable onboard antenna; Seeed ships a small 2.4GHz antenna that clips onto the U.FL/IPEX socket near the USB-C port. Without it the radio sees networks at roughly -85 dBm and cannot hold an association - `WiFi.status()` cycles 6 (disconnected) then sits at 0 (idle) rather than reaching 4 (auth failed), which reads like a credentials problem but is not one. Scan first and check RSSI before suspecting the password.
- Use USB serial at 115200 baud for diagnostics and upload. The board may disconnect and re-enumerate briefly during reset or upload.
- Before debugging the Pi serial protocol, prove the board independently: GPIO21 off at boot, touch-controlled LED output, and serial touch-state output.
- **Never wait unbounded on `while (!Serial)`.** The XIAO is routinely powered up before the Pi service opens the port, and an unbounded wait hangs the sketch inside `setup()` before anything runs - no output, no touch, no display, indistinguishable from a dead board. Bound it: `while (!Serial && millis() - start < 3000)`.
- The Grove OLED is a **SSD1315**, which is SSD1306-compatible. `U8G2_SSD1306_128X64_NONAME_F_HW_I2C oled(U8G2_R0, U8X8_PIN_NONE)` with `Wire.begin()` drives it. `oled.begin()` returns a bool - guard on it, and print the result, or a missing display is silent.
- A full U8g2 buffer push (`sendBuffer()`) costs roughly 10ms over I2C. Call it on state changes only; every loop starves the serial poll.
- **Never put a guard before the parse in a line handler.** `handleIncomingLine` opened with `if (!awaitingResponse) return;` *before* it deserialized anything, while the heartbeat deliberately never claims the pending slot - so every reply to a `device/status` was discarded unread, and a boot handshake that waited for one could never complete however many times it retried. Parse first, then decide what the message is for. The bug is invisible by inspection because both halves are individually correct.
- **A blocking peripheral read blocks everything, including the ability to notice a button was released.** `mic.readBytes()` for a whole 2-second clip made hold-to-talk impossible and froze any animation on its first frame. Read in ~100ms chunks and do the other work between them. A frozen indicator is worse than none: it asserts the device is busy while it may be dead, which is this project's most expensive failure mode.
- **Do not call a poll function from inside a handler that poll function dispatched.** `recordAndReportMic` calling `pollTouch()` to watch for release re-entered the function that owns the press/release debounce, leaving that state describing a moment that had already passed. Read the pad directly and debounce locally instead.
- **Batch `Serial.write`.** Writing 4 bytes at a time to the native USB CDC is ~107,000 calls for a 10-second audio clip and turns a transfer into a stall. Stage into a few hundred bytes and flush.
- **A large payload cannot be built in RAM before sending.** Ten seconds of audio is 320 KB of samples and ~427 KB of base64 - more than this chip's 320 KB of SRAM. Write the JSON by hand in pieces and encode on the way to the wire, straight out of PSRAM.
- **`cdc_on_boot=1` is the default for this board, and it is load-bearing for recovery.** The core brings the USB CDC stack up *before* `setup()` runs, and TinyUSB sits on its own FreeRTOS task that a spinning Arduino task cannot starve. That is why `/dev/ttyACM0` survives a sketch that hangs on the first line of `setup()`, and therefore why the Pi can flash a bricked device at all. A build with CDC-on-boot disabled could hang before USB exists, leaving no port to open.

## Building and flashing

```
arduino-cli compile --upload -p COM<n> firmware/smarttoolbox
```

No `--fqbn` needed: `firmware/smarttoolbox/sketch.yaml` declares a `release` profile
and sets it as the default, so the board, the `PSRAM=opi` option, and the pinned core
and library versions all come from there. Pass `--profile release` explicitly if you
prefer it visible in the command.

**A profile build ignores `~/Documents/Arduino/libraries` entirely.** It fetches the
pinned versions into a sketch-local directory instead. That is the point of it - an
`#include <ArduinoJson.h>` otherwise resolves to whatever is installed on the machine,
so updating a library for an unrelated project silently changes what ships. The first
profile build downloads its own core and toolchain and takes many minutes; later ones
reuse that cache.

The Grove 8x8 RGB matrix driver is **vendored into the sketch folder**
(`grove_two_rgb_led_matrix.h/.cpp`, MIT) rather than pinned in the profile, because it
is not in the Arduino library registry. The registry's similarly named "Grove - LED
Matrix Driver" is a different part - an STM32-based 64x32 dual-colour driver - and is
not a substitute. Provenance is recorded in `docs/SOURCES.md`.

To re-pin after a deliberate upgrade, build the way you normally would and run
`arduino-cli compile --fqbn esp32:esp32:XIAO_ESP32S3:PSRAM=opi --dump-profile
firmware/smarttoolbox`, then copy the versions it prints into `sketch.yaml`.

`arduino-cli board list` identifies the XIAO only as a generic "ESP32 Family Device"
with two candidate FQBNs. The COM port moves between sessions; compare the list with
the board unplugged to identify it.

### Resetting the board without reflashing

Some tests need a clean boot but must *not* reflash - checking that an OTA update is
picked up, for instance, where flashing over USB would install the new build directly
and prove nothing. Pulse RTS, which drives `EN` on the USB-Serial-JTAG bridge:

```powershell
$p = New-Object System.IO.Ports.SerialPort 'COM6',115200,'None',8,'One'
$p.Open()
$p.DtrEnable = $false; $p.RtsEnable = $true
Start-Sleep -Milliseconds 200
$p.RtsEnable = $false; $p.DtrEnable = $true
```

A successful reset prints `rst:0x15 (USB_UART_CHIP_RESET)` from the ROM bootloader.
Toggling DTR alone does **not** reset the board. After an OTA install the device
restarts itself, which shows as `rst:0xc (RTC_SW_CPU_RST)` - a useful way to confirm
the reboot came from `ESP.restart()` and not from something else.

### Flashing from the Pi over USB

The recovery path, for a build that OTA cannot replace - one that crashes in `setup()`,
wedges the loop, or breaks the serial link, where the thing that would accept the next
update is the thing that is broken. `api/scripts/flash-device.ps1` from Windows, or
`flash-device.sh` on the Pi. Proven against a real brick: a device silent for three
minutes came back in 47 seconds with nobody touching it.

- **`--no-stub` is mandatory on the Pi**, and its absence fails *late*. Debian ships
  `esptool` as `4.7.0+dfsg` with the precompiled stub flasher blobs stripped as non-free,
  so every command connects, resets the chip into download mode, identifies it, and only
  then dies with `FileNotFoundError: .../stub_flasher_32s3.json`. That reads like a
  corrupt installation rather than a licensing decision. Reaching that error is itself
  proof the hard part worked.
- **Install with `apt`, not `pip`.** The Pi's Python is externally managed under PEP 668.
  `sudo apt-get install -y esptool` gets 4.7.0; `--break-system-packages` is not worth it
  for a tool apt already has.
- **The binary is `/usr/bin/esptool`, not `esptool.py`,** and it is *not* on the PATH of a
  non-interactive SSH shell. Scripts must use the absolute path or they fail with
  `No such file or directory` while the same command works when typed by hand.
- **Flash the merged image, never the app binary.** `arduino-cli` writes
  `smarttoolbox.ino.merged.bin` beside `smarttoolbox.ino.bin`. The board is `default_8MB`
  with two app slots (`app0` at `0x10000`, `app1` at `0x340000`), so writing the app
  binary to `app0` while `otadata` points at `app1` reports complete success and changes
  nothing - the device boots the old image from the other slot. Writing the app binary at
  `0x0` is worse: it overwrites the bootloader and creates the brick you were fixing.
  `flash-device.sh` refuses anything under 2 MB for exactly this reason.
- The 8 MB image is not the transfer cost it looks like - it is mostly `0xFF` padding and
  compresses about 11:1, to ~736 KB. The ROM loader runs at ~2.6 Mbit/s: 26s writing, 48s
  wall clock including erase and reset.
- **Stop `smarttoolbox.service` first** to free the port, and restart it from a trap so it
  comes back even when the flash fails. A failed flash that also takes out the API, the
  dashboard and the serial link is worse than the failure it was reporting.
- The port re-enumerates during flashing - the USB device is provided by the chip being
  reprogrammed - so do not assume a stable device node across the whole operation.

### Testing an OTA update end to end

1. Note the version the device currently reports in its boot handshake.
2. `.\release-firmware.ps1 -Version <higher> -Push` from `api/scripts`.
3. Reset the board with the RTS pulse above - **not** by reflashing.
4. Watch for `OTA GET ... -> 200`, `OTA writing N bytes`, `OTA wrote N` (the two counts
   must match), then `rst:0xc`.
5. Confirm the next boot reports the new version and gets `-> 204`.

Step 5 is the actual proof. Steps 3 and 4 only show that bytes moved.

### Early boot output is written into a void

The S3's USB CDC is not a UART: anything `Serial.print`ed while no host has the port
open is **discarded, not buffered**. The device starts printing ~3.5s after power-on,
and the Pi's transport can still be in its reconnect backoff then, so boot-time output
routinely never reaches the log. This is not intermittent and it is not the Pi's fault.

The trap is that it makes a working code path look like a dead one. The OTA check
prints at every branch, and none of it survived - which was read for some time as "the
update check is not running". Anything that must be seen from the Pi has to be printed
*after* the link is proven, which is what `reportLastOtaResult()` is for: it holds the
outcome and prints it from `promoteToReady`, on the Pi's first reply. It used to fire on
the first heartbeat, which was an approximation of the same thing and is now wrong - the
waiting retry sends its first status two seconds after boot, and printing there would put
the log straight back into the void it was rescued from. The OLED is the only witness to
the boot window itself.

### The OTA boot check cannot win a cold start

Powering the whole box on at once guarantees a failed update check. The Pi needs 36.6s
to reach a listening API (5.2s kernel + 31.4s userspace); the device asks at ~3.5s and
gives up at ~30s, on the Wi-Fi timeout. It loses by about ten seconds, by construction,
every time.

It presents as `Update failed` on the OLED with a **negative** number - `HTTPClient`
returns its own error codes, so anything below zero means "never reached the server"
rather than a real HTTP status. Read the sign before anything else: negative is the
network or a server that is not up yet, `401` is the device key, `204` is genuinely up
to date.

To test an update deliberately, reset the XIAO **alone** against an already-running Pi.
Since 0.16.0 the device also re-checks two minutes after boot and every thirty minutes
while idle, so a cold start now recovers on its own rather than needing a second reset.

### HTTPClient discards response headers

`http.header("X-Firmware-Version")` returns an empty string unless the header was
requested *before* the request is sent:

```cpp
const char* wantedHeaders[] = {"X-Firmware-Version"};
http.collectHeaders(wantedHeaders, 1);
```

It fails silently, not loudly - the update still installs, it just cannot name the
version it installed.

### A large reply overflows the USB receive buffer, silently

The USB CDC receive buffer defaults to **256 bytes**. A found-tool reply from the Pi is
about a kilobyte and lands in under a millisecond, while the loop blocks for roughly
10ms at a time pushing a frame to the matrix over I2C. When the two coincide, one
buffer's worth of bytes is lost from the middle of the line - and the newline goes with
them, so what remains fuses with the next reply and `deserializeJson` rejects the pair.

Raise it before `Serial.begin()`, which is the only time it can be set:

```cpp
Serial.setRxBufferSize(4096);
Serial.begin(115200);
```

**The symptom names the wrong culprit.** The dropped line leaves the request pending, so
a hundred seconds later the voice timeout puts "No response - Is the Pi service up?" on
the screen, against a Pi that answered correctly and logged doing so. Small replies
survive and large ones do not, so "not found" works perfectly while every successful
lookup fails - which reads as a lookup bug rather than a transport one.

Found 2026-09-02, and only after `handleIncomingLine` was made to print what it could
not parse. It had been returning in silence, which is what made a damaged reply and a
missing reply indistinguishable. Keep that print.

### ESP-SR mono needs two settings, and half of it aborts the boot

`ESP_SR.begin()` defaults to stereo and an `"MN"` input format. This microphone is mono,
and mono is **two** arguments:

```cpp
ESP_SR.begin(mic, nullptr, 0, SR_CHANNELS_MONO, SR_MODE_WAKEWORD, "M");
//                             ^^^^^^^^^^^^^^^^                   ^^^
```

`SR_CHANNELS_MONO` sets the I2S channel count and `"M"` sets the AFE's feed format.
`sr_start` then runs `assert(feed_channel >= i2s_rx_chan_num)`. Pass one without the
other and that assert fires, which **aborts before `setup()` finishes** - so the symptom
is a device that will not start at all, with no serial output to say why. Nothing returns
an error and nothing logs.

### ESP-SR turns itself off after every detection

On a wake word, `esp32-hal-sr.c` calls `sr_set_mode(SR_MODE_OFF)` itself. Recognition
does not resume on its own. Without an explicit `setMode(SR_MODE_WAKEWORD)` in the
recovery path, **the box answers once and is then deaf** - identical from the outside to
a dead microphone, a frozen peripheral and a wrong threshold, which is the whole family
of failures the Debugging section of the spec exists to separate.

The first "Hi ESP" proves nothing. The second one is the test.

### Two readers on one I2SClass split the audio instead of failing

ESP-SR's feed task reads the microphone through the same `I2SClass` the recording loop
uses, and `ESP_SR.pause()` only sets event group bits - it is not synchronous. The feed
task may already be parked inside a blocking `readBytes`, and it passes `portMAX_DELAY`,
so it waits for a full chunk however long that takes.

Two consequences, and neither announces itself:

- **Drain the pause, do not trust it.** Wait out one in-flight chunk (~32ms) before reading. Otherwise both readers get alternating pieces and the recording is half a sentence with no error anywhere.
- **The feed task leaves `setTimeout(portMAX_DELAY)` on the shared object.** Any later `readBytes` in your own code inherits it and blocks forever on a stalled microphone rather than returning short. Set the timeout back explicitly before recording.

### A custom type in a function signature must be declared before the first function

Arduino generates forward prototypes and inserts them immediately before the **first
function definition in the sketch**. A type used in any signature has to be declared
above that line, not merely above the function that uses it.

The error names the wrong thing:

```
error: variable or field 'recordAndReportMic' declared void
error: 'VoiceTrigger' was not declared in this scope
```

`VoiceTrigger` was defined 130 lines above `recordAndReportMic` and still failed, because
`buttonPressed()` sits near the top of the file and the prototypes go in ahead of it.

### arduino-cli reports the wrong maximum with a custom partition table

A `partitions.csv` in the sketch folder overrides the board's partition scheme, and the
build honours it - the emitted `.partitions.bin` is correct. **The size report does not.**
It takes "Maximum is ..." from the board definition's `upload.maximum_size`, so with our
table it called a binary 65% of 3,342,336 bytes when it was 90.3% of 2,424,832.

A build that overflows the real app slot therefore compiles clean, reports two thirds
full, produces a merged image, and fails at the box. `release-firmware.ps1` reads the app
slot size out of `partitions.csv` and checks against that instead; do not trust the
compiler's percentage on this project.

### A partition change cannot ship over OTA, and the merged image does not carry the models

Two separate traps that arrive together:

- An over-the-air update writes an application into an app slot. It does not repartition flash. Anything that changes `partitions.csv` reaches the box over a USB cable or not at all.
- `arduino-cli` builds the merged image from the bootloader, partition table, otadata and application. It knows nothing about the `model` partition and leaves that region as `0xFF` - and `flash-device.sh` writes the whole 8 MB at offset 0. So **every USB flash silently erased the speech models** until `release-firmware.ps1` started splicing `srmodels.bin` in at the model offset. The recovery path was the thing that broke the feature.

The partition must be named exactly `model`: `sr_start()` calls
`esp_srmodel_init("model")` and looks at nothing else.

## Reference

Seeed documentation URL checked on 2026-08-27:
`https://wiki.seeedstudio.com/xiao_esp32s3_getting_started/`

The page identifies GPIO21 as `USER_LED`, documents active-low behavior, maps the exposed touch pads, and describes the factory touch-light program. The installed `XIAO_ESP32S3` board variant also maps `LED_BUILTIN` to GPIO21.

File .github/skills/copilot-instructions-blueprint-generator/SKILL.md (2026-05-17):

---
name: copilot-instructions-blueprint-generator
description: 'Technology-agnostic blueprint generator for creating comprehensive copilot-instructions.md files that guide GitHub Copilot to produce code consistent with project standards, architecture patterns, and exact technology versions by analyzing existing codebase patterns and avoiding assumptions.'
---

# Copilot Instructions Blueprint Generator

Technology-agnostic blueprint generator for creating comprehensive copilot-instructions.md files that guide GitHub Copilot to produce code consistent with project standards, architecture patterns, and exact technology versions by analyzing existing codebase patterns and avoiding assumptions.

## Configuration Variables

- `PROJECT_TYPE` - Auto-detect|.NET|Java|JavaScript|TypeScript|React|Angular|Python|Multiple|Other
- `ARCHITECTURE_STYLE` - Layered|Microservices|Monolithic|Domain-Driven|Event-Driven|Serverless|Mixed
- `CODE_QUALITY_FOCUS` - Maintainability|Performance|Security|Accessibility|Testability|All
- `DOCUMENTATION_LEVEL` - Minimal|Standard|Comprehensive
- `TESTING_REQUIREMENTS` - Unit|Integration|E2E|TDD|BDD|All
- `VERSIONING` - Semantic|CalVer|Custom

## Generated Prompt Template

Use this skill to analyze your codebase and generate a comprehensive copilot-instructions.md file that:

1. Detects exact technology versions
2. Documents architectural patterns
3. Catalogs coding standards
4. Captures testing approaches
5. Ensures consistency with existing code

The generated instructions will guide GitHub Copilot to:
- Respect exact versions of languages, frameworks, and libraries
- Follow established patterns in your codebase
- Maintain architectural consistency
- Apply appropriate quality standards
- Match your documentation and testing styles

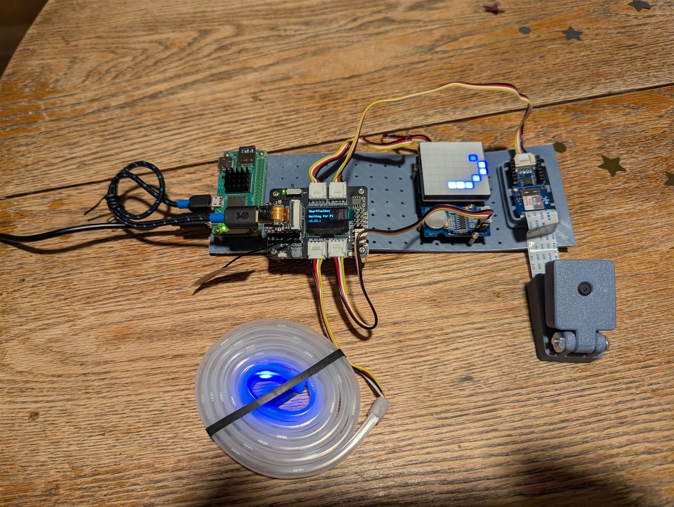
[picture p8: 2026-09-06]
docs/photos/wiring-2026-09-02.jpg

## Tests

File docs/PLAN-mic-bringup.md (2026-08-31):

---
title: Plan of Attack - Microphone Bring-Up (say a word, read it on the OLED)
scope: bring-up plan, written 2026-08-28 - PDM mic to Whisper to OLED, no tool matching
references: https://wiki.seeedstudio.com/xiao_esp32s3_sense_mic/
status: COMPLETE - proven by a human at the box 2026-08-29. Hold the pad, say a word, the
  OLED shows the word. Audio level is thin but workable; see "What the first real use
  showed" below.
---

# Plan: say a word, see the word

One sentence of scope:

> Hold the touch pad. Say "hammer". The OLED shows `hammer`.

That is the whole thing. **No tool matching, no drawer lookup, no row indication.** This
exists to prove the four unproven links in the chain before anything is built on top of
them, and to make each one fail on its own terms rather than as "nothing happened".

## Why this is separate from PLAN-voice-lookup.md

That plan builds the feature. This one proves the plumbing the feature assumes, and it
deliberately drops the hardest part of it.

`docs/PLAN-voice-lookup.md` Phase 1 is *transcript to tool name* - the fuzzy matching
that turns "needle nose pliers" into `Needle-nose Pliers`. That is the part with the most
design in it and the least hardware risk. This plan skips it entirely and keeps only the
parts nobody has ever run:

| Link | State today |
|---|---|
| PDM microphone initialised at all | **Never done in this sketch.** The spec's own advice: bring it up alone first |
| Audio off the device over serial | **Never done.** No binary of any size has crossed that link |
| Pi calling Whisper with real audio | **Never done.** Provider config and a reachability probe exist; no audio has passed through |
| A string coming back and reaching the OLED | **Never done** |

Everything this plan builds is reused by the voice-lookup plan. Nothing here is
throwaway except the OLED display of the raw transcript, which becomes a lookup call.

## Step 0 - is the microphone even attached? **Done 2026-08-28**

The Sense board is fitted, camera and mic facing up on the board-to-board connector, with
the Vision AI V2 still stacked on the expansion header below. **Both are on at once.**

An earlier revision of this plan and of the spec said only one of them could be present
and treated the camera as possibly displaced. That was wrong: they use different
connectors. Nothing here is blocked on it, and the pins are fixed by the board - GPIO 42
clock, GPIO 41 data.

## Step 1 - the mic records, and you can prove it from the serial log

Firmware only. The Pi is not involved and no audio leaves the device.

Initialise I2S in PDM mode, record a fixed two seconds into a buffer, and print
**statistics, not audio**: sample count, min, max, and RMS amplitude.

Confirmed against Seeed's own documentation - do not re-derive these:

```cpp
#include <ESP_I2S.h>            // Core 3.x. NOT the core-2.x <I2S.h>.
I2S.setPinsPdmRx(42, 41);       // 42 = clock, 41 = data
I2S.begin(I2S_MODE_PDM_RX, 16000, I2S_DATA_BIT_WIDTH_16BIT, I2S_SLOT_MODE_MONO);
```

**The library choice is the likeliest first failure.** Seeed's wiki still leads with the
core-2.x `I2S.h` API - `setAllPins`, `PDM_MONO_MODE`, `esp_i2s::i2s_read` - and this
project is on core 3.3.11, where none of that exists. If the first attempt does not
compile, check which half of that page was copied before debugging anything else.

**Mono and 16-bit are not choices.** The ESP32-S3 supports only PDM mono at 16-bit. The
sample rate is adjustable, but 16 kHz is both what Seeed reports as stable and what
Whisper wants, so leave it.

**`recordWAV` was the plan here, and it was dropped. Read this before putting it back.**
The intent was that one call returning a WAV-headered buffer would make Step 2 trivial.
Reading the core's implementation killed it: `recordWAV` allocates with plain `malloc`,
not `ps_malloc`, which directly contradicts the PSRAM instruction below - it takes the
64 KB from the S3's internal SRAM, of which this sketch already holds 49 KB of 320 KB.
It also takes a fixed duration, so it could never serve hold-to-talk anyway.

So Step 1 reads with `mic.readBytes()` into a `ps_malloc` buffer instead. That is fewer
moving parts for statistics, which need no header at all, and it is exactly the loop
hold-to-talk needs in Step 2 - the 44-byte header becomes the Pi's job, as Step 2
already assumed. Nothing is lost by the swap.

**Allocate in PSRAM.** Seeed's own example uses `ps_malloc` for this. Two seconds of
16 kHz 16-bit mono is 64 KB and four is 128 KB, against the XIAO's 320 KB of SRAM, of
which this sketch already uses 49 KB. Check the pointer - a silent allocation failure
looks exactly like a silent microphone.

**The build had PSRAM switched off, and still would have.** `ps_malloc` returns null on
every call unless `-DBOARD_HAS_PSRAM` is defined, and that comes from a board menu
option. `release-firmware.ps1` compiled with a bare `esp32:esp32:XIAO_ESP32S3`, and a
bare fqbn takes the *first* entry of each menu - which for PSRAM is `Disabled`. Every
binary ever released from this repo therefore had PSRAM off. The script now builds
`esp32:esp32:XIAO_ESP32S3:PSRAM=opi`.

This is the trap the paragraph above describes, arriving from the build rather than the
board, and it would have presented as a dead microphone. The firmware prints
`MIC error=psram-alloc-failed` and puts `Build PSRAM=opi` on the OLED rather than
letting a null pointer look like silence.

**Note for the OTA path:** this changes the binary for every build, not just mic ones.
The first release after this flag is the first PSRAM-enabled image the device will run.

**Done when:** RMS sits near a small constant in a quiet room and rises by an obvious
multiple when you speak into it. That single number separates "no data", "wrong pins",
and "working" - three failures that are otherwise identical.

**If it fails:** you have one variable. Nothing else in this plan has run yet.

### What was built - 2026-08-28

Firmware only, in `firmware/smarttoolbox/smarttoolbox.ino`:

- `MIC_BRINGUP`, a compile flag at the top of the sketch. While it is `1`, pad D0
  records and reports instead of running a tool lookup. The lookup path is proven and
  is untouched behind the `#else`; setting the flag to `0` restores it.
  **Superseded:** the flag is gone. Once the voice path shipped it was gating the
  feature rather than the bring-up - its off position deleted Feature 2, and no build
  had both halves working. Every pad now records; the lookup path is still reachable
  through `tools/lookup` and the `lookup <name>` serial command.
- `beginMicrophone()` - PDM RX on GPIO 42 clock / GPIO 41 data, 16 kHz, 16-bit, mono,
  via core 3.x `<ESP_I2S.h>`. Reports `Mic ready=0|1` at boot, the same shape as the
  existing `Matrix ready=` line.
- `recordAndReportMic()` - two seconds into PSRAM, then prints
  `MIC samples=N min=N max=N rms=N`. Plain text rather than JSON, so the Pi's existing
  `[serial-debug]` branch echoes it straight to the journal with no API change at all.
  RMS accumulates in a `uint64_t`: 32,000 squared 16-bit samples overflow 32 bits.

### First hardware run - 2026-08-28, in 0.15.0

It reached the device (the OTA story that took to get there is in
`docs/PLAN-ota-updates.md`) and the microphone came up:

```
Mic ready=1
MIC samples=32000 min=1025 max=2568 rms=1745
MIC samples=32000 min=981  max=2480 rms=1751
```

**What is proven:** PDM I2S initialises on GPIO 42/41, the PSRAM buffer allocates
(so `PSRAM=opi` is doing its job), and a full two seconds - all 32,000 samples -
reads back. Three of the four things that had never been done now work.

**What the numbers exposed:** the samples never cross zero. They run from about +981
to +2568, centred near +1745, because the PDM mic rides on a large positive DC bias.
RMS of the raw samples therefore measures that bias and not the sound, which is why two
separate recordings came back 1745 and 1751 - a number that barely moves is the offset,
not the room.

The plan's own gate caught this exactly as intended: "RMS near a small constant that
rises by an obvious multiple" is what a *working* measurement does, and this one was
constant for the wrong reason. Fixed in 0.17.0 by centring on the mean before squaring,
and `mean=` is now printed alongside `rms=` so the offset stays visible instead of
hiding inside the result.

**Still unproven, and this is the actual gate:** that a DC-corrected RMS is small in a
quiet room and multiplies when spoken into. Until that comparison is made, the mic is
known to produce *data*, not known to produce *audio*.

### The gate passed - 2026-08-29, in 0.19.0

Two presses, deliberately compared, in a quiet room:

```
MIC samples=32000 min=1524 max=1783 mean=1685 rms=17     # silence
MIC samples=32000 min=-1431 max=4068 mean=1665 rms=210   # "hammer"
```

**Twelve times.** The gate asked for "small in a quiet room, rising by an obvious
multiple when spoken into", and that is what it did.

The second line carries better evidence than the ratio, though. `min=-1431` is
**negative**, and no previous recording in this project has ever gone below zero - that
was the whole DC-bias discovery, samples riding on a +1665 offset and never crossing
zero. To read -1431 the signal had to swing more than 1,665 counts below its own centre.
Ambient noise does not do that. That is a voice.

**Step 1 is complete.** The microphone is no longer merely alive; it is proven to carry
audio. The four unproven links this plan was written to test are now three: recording
works, and what remains is getting the audio to the Pi, through Whisper, and back.

## The listening indicator - an animated sound wave

**Decided 2026-08-29.** While the box is recording, the matrix shows a travelling sound
wave: eight vertical bars in `green`, rising and falling across the panel. Recording is
the one state where the box is taking input rather than giving output, and it is the only
state a person has to actively participate in - they need to know the exact moment it is
listening, and "hold the pad and hope" is what they have today.

**Polychrome, and the only state on the panel that is.** Every other picture the box
draws is a single colour, so a wave that runs through four at once is unmistakable at a
glance - which is the entire job here, since the person has to know the exact moment it
is listening. It also sidesteps the colour-semantics problem rather than adding to it:
purple has meant "idle or thinking" and red and orange belong to results, so a
single-colour wave would have had to borrow one of them.

`drawSoundWave(uint8_t phase)`. Two tables.

**Heights - deliberately irregular.** A smooth repeating hump reads as a decoration
rather than as sound; real speech is uneven, and the picture should be too. Thirty-two
scattered values, indexed by column plus phase:

```
WAVE_HEIGHTS[32] = { 2,5,3,8,4,6,2,7,3,5,8,2,6,4,7,3,
                     5,2,8,4,3,6,2,5,7,3,4,8,2,6,3,5 }
height(x) = WAVE_HEIGHTS[(x + phase) % 32]
```

Thirty-two rather than eight for two reasons: at 100ms a step, a two-second recording is
twenty frames, so the table never visibly repeats inside a single recording - and being
fixed rather than randomised at run time, it can be tuned by eye instead of coming out
different on every press.

**Colour - a vertical ramp, by row rather than by column:**

```
WAVE_COLORS[8] = { cyan, blue, purple, pink, pink, purple, blue, cyan }
```

The centre line is pink and the edges cyan, so a tall bar reaches colours a short one
never shows. The palette itself then encodes amplitude, on top of the height - a loud
moment is both taller and more colourful, which is legible even at a glance from across
a workbench.

Each bar is **centred vertically**, not grown from the bottom - a centred wave reads as a
waveform, a bottom-anchored one reads as a bar chart. `top = (8 - height) / 2` in integer
arithmetic, so odd heights sit one row high of centre. That asymmetry is wanted: it is
part of what stops the wave looking machined.

`MATRIX_WAVE_STEP_MS = 100`, so a full 32-frame cycle takes 3.2 seconds.

**A later upgrade, deliberately not now:** once the read is chunked (below), each chunk
has a real RMS available, and the wave could be driven by the actual signal instead of a
table - scroll the array left and push the newest level in on the right. That is the
honest version and it is worth doing, but not before Step 1's gate has passed. A display
driven by a measurement nobody trusts yet would make a failing measurement look like a
working one.

### The trap: nothing can animate during `readBytes`

`recordAndReportMic()` records with a **single blocking** `mic.readBytes(..., 32000
bytes)` that does not return for the full two seconds. Add the wave without changing
that and it draws exactly one frame and freezes - which is this project's most expensive
failure mode, the one where a frozen peripheral and a working one look identical. A
frozen wave would be *worse* than no wave, because it would positively assert that the
box is listening while the panel is simply stuck.

So the wave requires the read to be chunked: read ~1,600 samples (100ms) at a time into
successive offsets of the same PSRAM buffer, and advance one wave phase between chunks.
Twenty `readBytes` calls instead of one, and 20 `matrixPush` calls at ~10ms of I2C each -
200ms of I2C inside a 2,000ms recording. That overhead lands between reads rather than
during them, so no samples are dropped, but it is real and it is the reason to keep the
wave to the recording window only.

Step 1's own comment already anticipates this: it notes that the hold-to-talk path in
Step 2 "reads in a loop instead, because there the length is not known when recording
starts". The wave brings that loop forward into Step 1, and the two changes want to
happen together.

**Done when:** holding the pad shows the wave crossing the panel for the whole
recording, and the reported `samples=` count is unchanged at 32000 - a wave that animates
but drops samples has traded the thing being built for the picture of it.

## What the first real use showed - 2026-08-29

Spoken to by a person, for the first time, on 0.21.2:

| held | rms | transcript |
|---|---|---|
| 2000ms | 175 | `8K47` |
| 1700ms | 119 | `Massachusetts.` |
| 1800ms | 384 | `Bill` |
| 3500ms | 71 | *(empty)* |

**It works.** "Massachusetts" was said deliberately to test how far it could be pushed,
and it came back exactly. The varying durations are hold-to-talk doing its job - none of
these is the old fixed two seconds.

**The plan's one-sentence scope is met**: hold the pad, say a word, see the word.

**What it also showed is that the audio is thin.** Take the first clip - `min=376
max=2873 mean=1684`. Deviation from centre is about +/-1,300 out of a 16-bit range of
+/-32,767: roughly **4% of full scale**, around -28 dBFS. The loudest reached ~10%.

The margin is real but narrow, and the last row is what it looks like when it runs out:
`rms=71` came back **empty**. Whisper is coping well with quiet audio rather than being
given good audio, and that will bite further from the box, in a noisier room, or with a
quieter speaker.

**Two things would widen it, and only the second is done:**

1. **Strip the DC offset and apply gain before sending.** The mic rides on a bias of
   ~+1,680 that is still in the transmitted samples, and nothing scales the signal up.
   The firmware already computes that mean for the RMS diagnostic - subtracting it,
   finding the peak deviation, scaling to ~80% of full scale and clamping would be worth
   roughly 8-10x on these clips. **Deliberately deferred**, not forgotten.
2. **Tell Whisper the language.** Done - `language=en` is now passed rather than letting
   Whisper guess, since detection on quiet audio is one more thing that can go wrong. It
   also came back measurably quicker: a one-second probe went from ~9.3s to ~6.8s, so
   detection was costing real time.

## Step 2 - the audio reaches the Pi and is playable

**Built 2026-08-29 in 0.20.0.** `sendVoiceAudio` streams one base64 line out of PSRAM;
`parseVoiceAudioBody` and `pcmToWav` in `api/src/voice.ts` decode it and prepend the
header. The base64 encoder was checked against Bun's at every length from 1 to 600 bytes,
which covers all three padding cases.

Send the recording to the Pi as **one line** of base64 raw PCM on a new `voice/audio`
serial endpoint, per PLAN-voice-lookup.md's wire format. The Pi decodes it, prepends the
44-byte WAV header, and writes the file to disk. Nothing else.

Two things in the transport must change first, and both are already known:

- **`SerialLineBuffer` needs a maximum line length.** It currently accumulates until a
  newline appears, with no bound. A 171 KB line is the first thing that has ever tested
  that, and a malformed sender would grow it without limit. Set a cap, reject the
  oversized line, clear the buffer, log a protocol error.
- **The `[serial-debug]` log must truncate.** Any non-JSON line is currently printed in
  full to the journal. One stray 171 KB line would be written verbatim to the SD card.

**Done when:** you can run `aplay` on the Pi against the written file and hear yourself
say the word. Not "the file exists" - hear it.

**Why this rung matters:** it separates *recording* failures from *transport* failures
from *transcription* failures. If the WAV plays back as noise, the mic setup is wrong. If
it never arrives, the line-length work is wrong. Whisper is not yet in the picture.

## Step 3 - Whisper returns a string, into the log

**Built 2026-08-29 in 0.20.0.** `transcribeAudio` in `api/src/voice.ts`. The NAS runs
`whisper-asr-webservice` 1.9.1; the endpoint is `POST /asr?task=transcribe&output=txt`
with a multipart `audio_file` field, taken from the service's own `/openapi.json` rather
than assumed - the field name differs from OpenAI's and a wrong one returns a bare 422.
Exercised end to end from a workstation against the real NAS before it reached the device:
~9.3s for one second of audio once warm, over 30s on the first call after an idle container.

The Pi posts the WAV to the configured provider and logs the transcript. Still no
response to the device.

The provider plumbing already exists: `/api/settings/transcription` stores the choice and
the NAS URL, and its reachability probe is already implemented and passing. This step
uses that configuration for the first time with real audio.

**Done when:** the Pi's journal shows the word you said.

**If it fails:** the failure is legible, because you already have a playable WAV from
Step 2. Feed that same file to the provider by hand with `curl`. If the manual call works
and the automatic one does not, the bug is in this project. If neither works, it is the
provider or the audio format, and the WAV in your hand tells you which.

## Step 4 - the string comes back and lands on the OLED

**Built 2026-08-29 in 0.20.0.** `handleVoiceResponse` in the sketch. An empty transcript
is treated as a real outcome rather than an error - it is what silence sounds like - and
the rms is still printed beside every recording, because it is the one number that
separates a quiet room from a broken microphone.

Answer the `voice/audio` request with the transcript, and have the firmware show it via
the existing `showStatus`.

The matrix already has a state for the wait: `startMatrixThinking()` is called when a
lookup goes out, and this should call it too - transcription is slower than a lookup, so
this is where a thinking face actually earns its place.

Two display facts worth deciding before writing it:

- The OLED is 0.96 inch. A long transcript will not fit; truncate at the display width
  rather than letting U8g2 clip it mid-glyph.
- An empty transcript is a real outcome, not an error. Whisper returns an empty string
  for silence, and the matrix already has the right picture for it: the question mark
  from `showMatrixUnknown`, which was drawn for exactly this case.

**Done when:** you hold the pad, say "hammer", and `hammer` appears on the screen.

## Trigger, and why it is not the button

Hold a touch pad, not the Grove Red LED Button. The button has nowhere to plug in - that
is the standing Open Hardware Question - and D0 is already calibrated, debounced, and
proven on hardware. `onTouchStart` already refuses to fire while a request is in flight,
which is exactly the guard a recording needs.

Hold-to-talk, per PLAN-voice-lookup.md Decision 3: record while held, 300 ms minimum,
10 s cap. The cap is not a nicety - it is what bounds the buffer allocated in Step 1.

## What this plan deliberately does not do

- **No tool matching.** The transcript is displayed raw. Turning it into a tool name is
  PLAN-voice-lookup.md Phase 1 and is unaffected by anything here.
- **No wake word.** Continuously classifying audio is a separate project.
- **No OpenAI fallback testing.** The provider switch exists and is configurable; prove
  one provider end to end before exercising the other.
- **No row indication.** Row indication is moving to the LED strip - see the Row
  Indication decision in the spec - and coupling this to it would tie a bring-up to
  hardware that is not wired.

## Everything must be tested on the Pi

The serial listener does not start on Windows, so no part of Steps 2 through 4 can be
exercised from the development machine. `cd api && .\sync.ps1` to deploy, and
`.\sync.ps1 -Status` to read the service log.

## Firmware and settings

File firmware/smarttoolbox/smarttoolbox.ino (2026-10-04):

/**
 * SmartToolbox - Seeed XIAO ESP32S3 Firmware
 *
 * Holding the expansion base's button sends a tools/lookup request to the Pi
 * serial and reports the result three ways: the onboard LED blinks N slow for
 * the row number, 3 fast for not found, 1 long for error or timeout; the OLED
 * names the tool and its exact drawer label; and the 8x8 matrix lights the
 * matching row, showing idle "eyes" the rest of the time.
 *
 * The matrix is wired and detected. Its code stays inert until the VID check
 * passes, so a box without one behaves exactly as it did before.
 */

#include <ArduinoJson.h>
#include <Wire.h>
#include <U8g2lib.h>
#include "grove_two_rgb_led_matrix.h"
#include <WiFi.h>
#include <HTTPClient.h>
#include <Update.h>
#include <ESP_I2S.h>
#include <ESP_SR.h>
#include <Adafruit_NeoPixel.h>
#include "arduino_secrets.h"

// Single source of truth for the version this build reports. Rewritten by
// api/scripts/release-firmware.ps1 on release, and compared against the Pi's
// drop folder to decide whether an OTA update is available - keep the exact
// `#define FIRMWARE_VERSION "x.y.z"` shape so the script can find it.
#define FIRMWARE_VERSION "0.28.0"

// Which trigger started a voice capture. The two differ only in how the
// recording ends - the button on its own release, the wake word on a clock -
// but that is enough that the capture loops cannot be one function with a flag
// in it.
//
// Declared up here rather than beside the microphone constants it belongs with,
// because Arduino inserts its generated forward prototypes immediately before
// the first function definition in the sketch. A type named in any signature
// has to exist above that line. The compiler reports it as
// "variable or field 'recordAndReportMic' declared void", which does not
// mention the enum at all.
enum VoiceTrigger {
  VOICE_TRIGGER_BUTTON,
  VOICE_TRIGGER_WAKEWORD
};

const int LED_PIN = LED_BUILTIN; // Active-low: LOW = on, HIGH = off.
const int LED_ON = LOW;
const int LED_OFF = HIGH;

// The expansion base's onboard 0.96" OLED, on the shared I2C bus at 0x3C. This
// used to be the Grove SSD1315 on the XIAO's own I2C pins; the base carries an
// SSD1306 at the same address, so the panel changed and this line did not - the
// two cannot both be on the bus, which is why the Grove one came off.
U8G2_SSD1306_128X64_NONAME_F_HW_I2C oled(U8G2_R0, U8X8_PIN_NONE);
bool oledReady = false;

// 128px wide in a 6px font, so 21 characters is the line. Whisper returns a whole
// sentence and the screen shows what fits; the transcript also goes out over
// serial in full, which is where a long one is actually readable.
//
// Declared up here rather than beside the code that uses it, because the lookup
// result branches truncate with it too and they run earlier in the file.
const size_t OLED_LINE_CHARS = 21;

// Grove 8x8 RGB matrix, on the same I2C bus. matrixReady comes from the VID
// check, and every matrix call returns early without it, so a box with no matrix
// attached behaves exactly as it did before this existed.
GroveTwoRGBLedMatrixClass matrix;
bool matrixReady = false;

// One byte per pixel, and the byte is a palette index rather than RGB. Note
// black is 0xFF: clearing this buffer with zeroes lights the whole panel red.
const uint8_t MATRIX_WIDTH = 8;
const uint8_t MATRIX_HEIGHT = 8;
uint8_t matrixFrame[MATRIX_WIDTH * MATRIX_HEIGHT];
bool matrixFrameDirty = false;

// Toolbox row N lights matrix row y = N, leaving y=0 and y=7 as blank margins so
// the six indicators sit centred. Six positions for eight rows is the spec's
// Physical Layout rule: row 1 is one shared indicator for drawers 1A/1B/1C.
const uint8_t MATRIX_FIRST_ROW_Y = 1;
const uint8_t MATRIX_LAST_ROW_Y = 6;

// Orientation is stored on the matrix itself and survives power cycles, so
// without setting it explicitly the panel renders at whatever rotation it was
// last left in - which differs between boards and after any stray write. Set it
// every boot so "row 1" always means the same physical row. Rotate this if the
// eyes and the row indicator do not sit the way up the built-in displayNumber()
// output does.
const orientation_type_t MATRIX_ORIENTATION = DISPLAY_ROTATE_270;

// --- WS2813 row indicator strip ----------------------------------------------
//
// Grove WS2813, 30 LED/m, 1m (SKU 104020108), on the expansion base's UART Grove
// port. Nothing in this sketch uses UART0 - Serial is the native USB CDC port -
// so the pins are free.
//
// **DIN is GPIO44, BIN is GPIO43.** Proven on hardware 2026-09-02 by driving
// each pin in turn and watching which one the strip answered on. That also
// explains the pixel that lights at power-up before the sketch runs: the boot
// ROM prints its log on GPIO43, which is the backup input, and a WS2813 falls
// back to that line when the main one is idle. The first write clears it.
const uint8_t STRIP_DATA_PIN = 44;  // D7, UART0 RX.
const uint16_t STRIP_LED_COUNT = 30;

// The base's Grove ports are silkscreened 3V3 and a WS2813 wants 5V, so these
// LEDs run under-volted: the colours skew and the top of the range is not there.
// Kept low anyway, because every lit LED draws through the XIAO's regulator on
// the Pi's USB feed. Read the power note in docs/HARDWARE.md before raising it.
const uint8_t STRIP_BRIGHTNESS = 40;

// Row N lights LED N-1. A placeholder: one LED beside each row is the whole
// argument for the strip, but which LED ends up beside which drawer is a
// physical fact nobody has fixed yet, because the strip is still on the bench.
const uint16_t STRIP_ROW_FIRST_LED = 0;

Adafruit_NeoPixel strip(STRIP_LED_COUNT, STRIP_DATA_PIN, NEO_GRB + NEO_KHZ800);

// --- Push-to-talk button -----------------------------------------------------
//
// The expansion base's own button, on D1. It shorts the pin to ground and the
// base carries no pull-up of its own, so the internal one holds it high and a
// press reads LOW.
//
// This replaced the D0 touch pad, which the PIR now drives from the base's A0/D0
// Grove port: touch charges a pad while the sensor drives it, which is two
// drivers on one net. The pads are still on the board and still touch-capable,
// but nothing here reads them, so the baselines, the trigger ratio and the
// per-scan debug print went with the pad. What that machinery taught is recorded
// in .github/instructions/xiao-esp32s3-firmware.instructions.md, which is where
// the next person to reach for a pad will look.
const uint8_t BUTTON_PIN = 2; // D1 on the XIAO ESP32S3.

bool buttonPressed() {
  return digitalRead(BUTTON_PIN) == LOW;
}

const uint16_t RESPONSE_TIMEOUT_MS = 2000;

// Transcription is not a lookup and cannot share its timeout. Measured against
// the NAS on 2026-08-29: ~9.3s for one second of audio once warm, and well over
// 30s on the first call after the container has been idle and has to load the
// model. The Pi gives up at 90s; this is deliberately longer, so the device is
// never the one to abandon a request the Pi is still working on.
const uint32_t VOICE_TIMEOUT_MS = 100000;
bool pendingIsVoice = false;

// Wi-Fi is used for OTA updates only, and only during setup(). USB serial stays
// the link for everything else, so the radio is switched off before loop() runs
// rather than left associated for the device's whole uptime.
// Deliberately breaks the device, to prove the USB recovery path works on
// something that is actually broken rather than on a device that was fine all
// along. See docs/PLAN-usb-flashing.md Step 3.
//
// With this set, setup() hangs on its first line - before Serial.begin, before
// the OLED, before anything. No serial link, no heartbeat, no OTA check: every
// software update path this project has is dead, which is the whole point. Only
// the ROM bootloader can help, and that is exactly the claim being tested.
//
// **This must never be released.** It exists to be set to 1 by hand, flashed
// over USB, and then flashed back over.
#define BRICK_TEST 0

#define OTA_ENABLED 1
const char* PI_HOST = "192.168.50.30";
const uint16_t PI_PORT = 3000;
const uint32_t WIFI_CONNECT_TIMEOUT_MS = 25000;

// Thirty seconds is a compromise: often enough that the dashboard reads as live
// and a reboot is noticed promptly, rare enough that it is not worth writing
// every one of them to the request log.
const uint32_t DEVICE_STATUS_INTERVAL_MS = 30000;
uint32_t nextDeviceStatusAt = 0;
unsigned long statusCounter = 0;

// --- Startup readiness -------------------------------------------------------
//
// Both halves of the box boot from the same power and do not arrive together:
// this device is up in seconds, the Pi takes 36.6s (5.2s kernel + 31.4s
// userspace) before its API accepts anything. For that whole window the box
// used to say "Ready" and mean nothing by it - a touch went into a void and
// came back "No response - Is the Pi service up?", which is a question the
// device is not entitled to ask while the Pi is merely booting.
//
// So the fast half waits. Nothing here changes on the Pi: there is nothing it
// can do about a 31-second userspace, and a device that copes is worth more
// than a server that hurries. See docs/PLAN-startup-readiness.md.
bool deviceReady = false;

// Far more frequent than the 30s heartbeat on purpose: this window is ~35
// seconds long, and a 30-second poll would spend most of it asleep.
const uint32_t WAITING_RETRY_MS = 2000;
uint32_t nextWaitingRetryAt = 0;

// There is no timeout that gives up - a Pi that takes five minutes gets waited
// for. But 90 seconds is well past anything a healthy boot has ever taken, so
// past that the face stops pretending this is normal. It is a change of
// expression, not a failure state: the retry continues either way.
const uint32_t WAITING_LONG_MS = 90000;
uint32_t waitingSince = 0;
bool waitingLong = false;

// The boot check alone let three releases go by unnoticed: the device only
// looked for an update in the first seconds after power-on, so a box that
// stayed up never learned a new version existed. Re-checking on an interval is
// what makes a release actually reach a running device.
//
// Thirty minutes, and only while idle. The check costs up to
// WIFI_CONNECT_TIMEOUT_MS of blocked loop when the radio cannot associate, so
// it must never land in the middle of a lookup the user is waiting on.
const uint32_t FIRMWARE_CHECK_INTERVAL_MS = 30UL * 60UL * 1000UL;

// The boot check cannot succeed when the whole box is powered on at once, and
// this is measured rather than suspected: the Pi takes 36.6s to finish booting
// (5.2s kernel + 31.4s userspace) before its API accepts anything, while this
// device starts asking ~3.5s in and gives up after the 25s Wi-Fi timeout, at
// roughly 30s. It loses by about ten seconds, every time, by construction.
//
// So the first re-check is deliberately soon rather than a full interval: by
// two minutes the Pi is up with a wide margin. Updates used to work only
// because the XIAO was being reset by itself against an already-running Pi.
const uint32_t FIRMWARE_FIRST_CHECK_MS = 2UL * 60UL * 1000UL;
uint32_t nextFirmwareCheckAt = 0;

// What the last update check actually did. Kept because the check runs before
// the Pi has opened the port: on the S3's native USB CDC, anything printed
// while no host is attached is discarded, so the boot-time OTA log is lost
// every time. Holding the outcome and printing it once the link is up is the
// difference between a diagnosable failure and silence.
String lastOtaResult = "not checked";
bool lastOtaResultReported = false;

// --- Microphone (PDM, on the XIAO Sense expansion board) ---------------------
//
// Holding a pad records; releasing it sends the audio to the Pi to be
// transcribed and looked up. The statistics line the bring-up was built around
// still goes out alongside the transcript - see recordAndReportMic - because it
// is the one number that separates "no data", "wrong pins" and "working", three
// failures that are otherwise identical from the outside.

// Fixed by the Sense board's board-to-board connector - not free choices.
const int8_t MIC_CLOCK_PIN = 42;
const int8_t MIC_DATA_PIN = 41;

// None of these three are choices either: the ESP32-S3 supports PDM only as
// 16-bit mono, and 16 kHz is both what Seeed reports as stable and the rate
// Whisper wants, so resampling never enters the picture.
const uint32_t MIC_SAMPLE_RATE = 16000;
const uint8_t MIC_BYTES_PER_SAMPLE = 2;
// Hold-to-talk. The length is not known when recording starts, so the buffer is
// allocated at the cap and only the filled part is sent.
//
// 300ms floor: below that it is a brush against the pad rather than a word, and
// Whisper on a fragment that short returns confident nonsense - which is worse
// than nothing, because it looks like an answer. 10s ceiling: it bounds this
// allocation, and it is what the Pi's own cap agrees with.
const uint32_t MIC_MIN_HOLD_MS = 300;
const uint32_t MIC_MAX_HOLD_MS = 10000;
const size_t MIC_MAX_BYTES = (size_t)MIC_SAMPLE_RATE * MIC_BYTES_PER_SAMPLE * (MIC_MAX_HOLD_MS / 1000);

// Read in ~100ms pieces rather than one blocking gulp. Two things need this:
// the wave cannot animate during a read that does not return, and hold-to-talk
// cannot notice the pad being released either. A single readBytes for the whole
// recording made both impossible.
const size_t MIC_CHUNK_BYTES = (size_t)MIC_SAMPLE_RATE * MIC_BYTES_PER_SAMPLE / 10;

I2SClass mic;
bool micReady = false;
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
void loop() {
  pollButton();
  pollWakeWord();
  pollSerialResponses();
  pollResponseTimeout();
  pollWaitingRetry();
  pollWaitingLong();
  pollDeviceStatus();
#if OTA_ENABLED
  pollFirmwareUpdate();
#endif
  updateBlinkPlan();
  updateMatrix();
}

// Throttled to ~50ms, which is also the debounce interval below. A mechanical
// button bounces for a millisecond or two; reading it every 50ms and requiring
// two agreeing reads puts the decision well clear of that.
void pollButton() {
  static uint32_t lastScan = 0;
  if (millis() - lastScan < 50) {
    return;
  }
  lastScan = millis();

  if (buttonPressed()) {
    consecutivePressed++;
    consecutiveReleased = 0;
  } else {
    consecutivePressed = 0;
    consecutiveReleased++;
  }

  // Debounce both edges. Press needs 2 consecutive readings; release needs 2 as
  // well, so a single noisy sample mid-press cannot end the press and re-arm the
  // next one.
  const bool isPressed = wasPressed ? consecutiveReleased < 2 : consecutivePressed >= 2;
  if (isPressed && !wasPressed) {
    onButtonPress();
  }
  wasPressed = isPressed;
}

// Only start a new recording when idle - not already waiting on a lookup or
// blinking its result. Shared by both triggers, because a wake word arriving
// mid-lookup is the same mistake as a second button press and deserves the same
// answer.
bool voiceCaptureAllowed() {
  if (awaitingResponse || blinkRemaining > 0) {
    return false;
  }

  // A press here is someone asking "is it on?", and the honest answer is already
  // on the screen. Recording anyway would spend ten seconds and come back "No
  // response", blaming a Pi that is merely booting. This guard used to sit
  // inside the lookup path so that microphone bring-up stayed testable on a
  // bench where nothing answered; the bring-up is done, and the box's job now
  // needs the Pi like any other.
  if (!deviceReady) {
    showWaitingStatus();
    return false;
  }

  return true;
}

// Picks up the flag onSpeechEvent set on the SR handler task, so the recording
// runs on loop() where every other long job in this sketch runs.
//
// The flag is cleared whether or not the capture is allowed to start. A wake
// word heard while the box was busy is stale by the time it could be acted on,
// and queueing it would start a recording seconds later with nobody speaking.
void pollWakeWord() {
  if (!wakeWordHeard) {
    return;
  }
  wakeWordHeard = false;

  if (!voiceCaptureAllowed()) {
    return;
  }

  wakeCaptureCount++;
  recordAndReportMic(VOICE_TRIGGER_WAKEWORD);
}

void onButtonPress() {
  if (!voiceCaptureAllowed()) {
    return;
  }

  // Hold the button, say what you want, and the drawer comes back on the OLED
  // and the matrix. That is the whole of Feature 2 and the only thing the button
  // does.
  //
  // A hard-coded tool name per pad used to live here behind MIC_BRINGUP=0, from
  // before the microphone worked. It was a compile flag whose off position
  // deleted the shipped feature, and there was no build in which both halves
  // worked. The lookup path it exercised is unchanged and still reachable two
  // other ways: the Pi's tools/lookup endpoint, and "lookup <name>" typed into a
  // serial monitor - see handleIncomingLine.
  recordAndReportMic(VOICE_TRIGGER_BUTTON);
}

void sendToolLookupRequest(const char* toolName) {
  requestCounter++;
  char idBuffer[16];
  snprintf(idBuffer, sizeof(idBuffer), "req-%lu", (unsigned long)requestCounter);

  JsonDocument doc;
  doc["id"] = idBuffer;
  doc["type"] = "request";
  doc["endpoint"] = "tools/lookup";
  doc["body"]["query"] = toolName;

  serializeJson(doc, Serial);
  Serial.print('\n');

  pendingRequestId = idBuffer;
  pendingToolName = toolName;
  pendingSince = millis();
  awaitingResponse = true;
  pendingIsVoice = false;

  showStatus("Looking up", pendingToolName, "");
  startMatrixThinking();
}

// The Pi only ever hears from this device when someone uses it, so without a
// heartbeat the dashboard cannot tell "idle" from "unplugged", and the firmware
// version it reports is whatever it last managed to announce. That announcement
// is unreliable by nature: it goes out while the USB serial port is still
// re-enumerating after a reset, so the Pi is frequently not listening yet.
// Repeating it fixes both - a lost boot message costs one interval, not a
// version.
void sendDeviceStatus() {
  statusCounter++;
  char idBuffer[24];
  snprintf(idBuffer, sizeof(idBuffer), "status-%lu", (unsigned long)statusCounter);

  JsonDocument doc;
  doc["id"] = idBuffer;
  doc["type"] = "request";
  doc["endpoint"] = "device/status";
  doc["body"]["firmwareVersion"] = FIRMWARE_VERSION;
  // The Pi spots a restart by watching this run backwards, which works even when
  // the message sent at boot never arrived.
  doc["body"]["uptimeMs"] = millis();

  serializeJson(doc, Serial);
  Serial.print('\n');

  nextDeviceStatusAt = millis() + DEVICE_STATUS_INTERVAL_MS;
}

// Deliberately does not set awaitingResponse or pendingRequestId. This is fire
// and forget: the Pi's reply carries an id no one is waiting on, which
// handleLookupResponse already ignores, and claiming the pending slot would make
// a heartbeat cancel a lookup the user is waiting for.
void pollDeviceStatus() {
  if (!deviceReady || awaitingResponse || millis() < nextDeviceStatusAt) {
    return;
  }

  sendDeviceStatus();
}

// The boot handshake: keep asking every two seconds until something answers.
//
// Deliberately without the awaitingResponse guard that pollDeviceStatus uses.
// That guard is right for a heartbeat and fatal here - one unanswered request
// would wedge the device in WAITING forever, which is precisely the failure
// this whole path exists to remove. Nothing sets awaitingResponse during
// WAITING anyway except the serial bench trigger, and this must survive that
// too.
void pollWaitingRetry() {
  if (deviceReady || millis() < nextWaitingRetryAt) {
    return;
  }

  nextWaitingRetryAt = millis() + WAITING_RETRY_MS;
  sendDeviceStatus();
}

// The boot-time OTA log never survives: the check runs before the Pi has the
// port open, and the S3's USB CDC discards writes with no host attached. So it
// is held and printed once the link is proven.
//
// Called from promoteToReady, which is that moment exactly - a reply has come
// back. It used to fire on the first heartbeat, which was an approximation of
// the same thing and is now wrong: the waiting retry sends its first status two
// seconds after boot, and printing there would put the log straight back into
// the void it was rescued from.
// Plain text, so it lands in the Pi's [serial-debug] with no API change.
void reportLastOtaResult() {
  if (lastOtaResultReported) {
    return;
  }
  lastOtaResultReported = true;

  Serial.print("OTA last result: ");
  Serial.println(lastOtaResult);
}

#if OTA_ENABLED
// Idle-only, for the reason given at FIRMWARE_CHECK_INTERVAL_MS: a failed
// association blocks the loop for the whole Wi-Fi timeout, and doing that
// underneath a lookup would read as the device freezing.
void pollFirmwareUpdate() {
  if (awaitingResponse || blinkRemaining > 0 || millis() < nextFirmwareCheckAt) {
    return;
  }

  nextFirmwareCheckAt = millis() + FIRMWARE_CHECK_INTERVAL_MS;
  checkForFirmwareUpdate(); // Reboots into the new image if one was written.

  // Only reached when no update was taken. The check leaves its own outcome on
  // the OLED, which is the wrong screen for a box that is still waiting.
  if (!deviceReady) {
    showWaitingStatus();
  }
}
#endif

void pollSerialResponses() {
  while (Serial.available() > 0) {
    const char incomingChar = (char)Serial.read();
    if (incomingChar == '\n') {
      handleIncomingLine(serialLineBuffer);
      serialLineBuffer = "";
    } else if (incomingChar != '\r') {
      serialLineBuffer += incomingChar;
    }
  }
}
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

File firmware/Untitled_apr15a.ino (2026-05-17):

#include "arduino_secrets.h"
#include <eloquent_esp32cam.h>
#include <U8g2lib.h>
// #include <MUIU8g2.h>
#include <U8x8lib.h>


#include <Wire.h>
#include "Seeed_Arduino_SSCMA.h"
#include "grove_two_rgb_led_matrix.h"
#include "thingProperties.h"

#ifdef ARDUINO_SAMD_VARIANT_COMPLIANCE
#define SERIAL_PORT_MONITOR SerialUSB
#else
#define SERIAL_PORT_MONITOR Serial
#endif

GroveTwoRGBLedMatrixClass matrix;
SSCMA AI;

bool matrixReady = false;
bool visionReady = false;
bool personDetected = false;
int highestPersonScore = 0;
unsigned long lastVisionPollMs = 0;

const uint8_t PERSON_TARGET_ID = 0;
const uint8_t PERSON_SCORE_THRESHOLD = 60;
const unsigned long VISION_POLL_INTERVAL_MS = 500;

U8G2_SSD1306_128X64_NONAME_F_HW_I2C u8g2(U8G2_R0, /* reset= */ U8X8_PIN_NONE);
bool oledReady = false;

enum DisplayType { DISP_OFF, DISP_COLOR, DISP_EMOJI, DISP_NUMBER };
DisplayType displayType = DISP_OFF;
uint32_t displayColorRgb = 0;
uint8_t displayEmojiIndex = 0;
int16_t displayNumber = 0;

// Last-sent state — only update matrix when something changes
DisplayType lastSentType = DISP_OFF;
uint32_t lastSentColorRgb = 0;
uint8_t lastSentEmojiIndex = 0xFF;
int16_t lastSentNumber = 0;
bool lastSentPersonDetected = false;

void parseMatrixDisplay(const String& val) {
  String v = val;
  v.trim();
  v.toLowerCase();

  // Colors
  if (v == "" || v == "off")  { displayType = DISP_OFF;   return; }
  if (v == "red")    { displayType = DISP_COLOR; displayColorRgb = 0xFF0000; return; }
  if (v == "orange") { displayType = DISP_COLOR; displayColorRgb = 0xFF8000; return; }
  if (v == "yellow") { displayType = DISP_COLOR; displayColorRgb = 0xFFFF00; return; }
  if (v == "green")  { displayType = DISP_COLOR; displayColorRgb = 0x00FF00; return; }
  if (v == "cyan")   { displayType = DISP_COLOR; displayColorRgb = 0x00FFFF; return; }
  if (v == "blue")   { displayType = DISP_COLOR; displayColorRgb = 0x0000FF; return; }
  if (v == "purple") { displayType = DISP_COLOR; displayColorRgb = 0xFF00FF; return; }
  if (v == "white")  { displayType = DISP_COLOR; displayColorRgb = 0xFFFFFF; return; }

  // Emojis
  if (v == "smile")  { displayType = DISP_EMOJI; displayEmojiIndex = 0;  return; }
  if (v == "laugh")  { displayType = DISP_EMOJI; displayEmojiIndex = 1;  return; }
  if (v == "sad")    { displayType = DISP_EMOJI; displayEmojiIndex = 2;  return; }
  if (v == "mad")    { displayType = DISP_EMOJI; displayEmojiIndex = 3;  return; }
  if (v == "angry")  { displayType = DISP_EMOJI; displayEmojiIndex = 4;  return; }
  if (v == "cry")    { displayType = DISP_EMOJI; displayEmojiIndex = 5;  return; }
  if (v == "cool")   { displayType = DISP_EMOJI; displayEmojiIndex = 7;  return; }
  if (v == "heart")  { displayType = DISP_EMOJI; displayEmojiIndex = 10; return; }
  if (v == "flame")  { displayType = DISP_EMOJI; displayEmojiIndex = 14; return; }
  if (v == "duck")   { displayType = DISP_EMOJI; displayEmojiIndex = 27; return; }
  if (v == "cat")    { displayType = DISP_EMOJI; displayEmojiIndex = 29; return; }
  if (v == "up")     { displayType = DISP_EMOJI; displayEmojiIndex = 30; return; }
  if (v == "down")   { displayType = DISP_EMOJI; displayEmojiIndex = 31; return; }
  if (v == "left")   { displayType = DISP_EMOJI; displayEmojiIndex = 32; return; }
  if (v == "right")  { displayType = DISP_EMOJI; displayEmojiIndex = 33; return; }

  // Number (e.g. "42", "-5")
  bool isNum = (v.length() > 0);
  uint8_t start = (v[0] == '-' || v[0] == '+') ? 1 : 0;
  if (v.length() <= start) isNum = false;
  for (uint8_t i = start; i < v.length() && isNum; i++) {
    if (!isDigit(v[i])) isNum = false;
  }
  if (isNum) {
    displayType = DISP_NUMBER;
    displayNumber = (int16_t)constrain(v.toInt(), -32767, 32767);
    return;
  }

  displayType = DISP_OFF;
}



bool visionSeesPerson() {
  if (!visionReady) return false;
  
  highestPersonScore = 0;
  
  for (size_t i = 0; i < AI.boxes().size(); i++) {
    if (AI.boxes()[i].target == PERSON_TARGET_ID) {
      if (AI.boxes()[i].score > highestPersonScore) {
        highestPersonScore = AI.boxes()[i].score;
      }
    }
  }
  
  for (size_t i = 0; i < AI.classes().size(); i++) {
    if (AI.classes()[i].target == PERSON_TARGET_ID) {
      if (AI.classes()[i].score > highestPersonScore) {
        highestPersonScore = AI.classes()[i].score;
      }
    }
  }
  
  return highestPersonScore >= PERSON_SCORE_THRESHOLD;
}

void updateVisionDetection() {


  if (!visionReady) return;
  if (millis() - lastVisionPollMs < VISION_POLL_INTERVAL_MS) return;

  int invokeResult = AI.invoke(1, false, false);
  if (invokeResult != 0) {
    SERIAL_PORT_MONITOR.print("Invoke failed: ");
    SERIAL_PORT_MONITOR.println(invokeResult);
    delay(200); // brief back-off before next attempt
    return;
  }

  lastVisionPollMs = millis();

  if (invokeResult != 0) {
    SERIAL_PORT_MONITOR.print("Invoke failed: ");
    SERIAL_PORT_MONITOR.println(invokeResult);
    return;
  }

  SERIAL_PORT_MONITOR.print("boxes: ");
  SERIAL_PORT_MONITOR.print(AI.boxes().size());
  SERIAL_PORT_MONITOR.print("  classes: ");
  SERIAL_PORT_MONITOR.println(AI.classes().size());

  bool detectedNow = visionSeesPerson();
  SERIAL_PORT_MONITOR.print("Highest person score: ");
  SERIAL_PORT_MONITOR.println(highestPersonScore);

  if (detectedNow != personDetected) {
    personDetected = detectedNow;
    SERIAL_PORT_MONITOR.print("Vision person detected: ");
    SERIAL_PORT_MONITOR.println(personDetected ? "YES" : "NO");
  }

  if (personConfidence != highestPersonScore) {
    personConfidence = highestPersonScore;
  }
}

void updateMatrixOutput() {
  if (!matrixReady) {
    return;
  }

  if (personDetected) {
    if (!lastSentPersonDetected) {
      matrix.displayColorBlock(0x00FF00, 0, true);
      lastSentPersonDetected = true;
    }
    return;
  }
  lastSentPersonDetected = false;

  if (displayType == lastSentType
      && (displayType != DISP_COLOR  || displayColorRgb  == lastSentColorRgb)
      && (displayType != DISP_EMOJI  || displayEmojiIndex == lastSentEmojiIndex)
      && (displayType != DISP_NUMBER || displayNumber     == lastSentNumber)) {
    return; // nothing changed
  }

  switch (displayType) {
    case DISP_COLOR:
      matrix.displayColorBlock(displayColorRgb, 0, true);
      lastSentColorRgb = displayColorRgb;
      break;
    case DISP_EMOJI:
      matrix.displayEmoji(displayEmojiIndex, 0, true);
      lastSentEmojiIndex = displayEmojiIndex;
      break;
    case DISP_NUMBER:
      matrix.displayNumber(displayNumber, 0, true, 0xfe);
      lastSentNumber = displayNumber;
      break;
    case DISP_OFF:
    default:
      matrix.stopDisplay();
      break;
  }
  lastSentType = displayType;
}
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

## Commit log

2026-08-27 Reconcile the project spec with the implemented code
    copilot-instructions.md described endpoints, tables, and pin mappings
    that were never built, with nothing marking them as aspirational.
    Added a per-section Status tag (Implemented/Partial/Planned/Blocked)
    and corrected the file against api/src and the real hardware state.
    Also: track sync.ps1 (was gitignored, made paths repo-relative so it
    works from any clone), add docs/SOURCES.md as an index for vendor
    datasheets (the PDFs themselves stay gitignored), and add
    docs/PLAN-next-features.md.
    Claude-Session: https://claude.ai/code/session_01Rn9dqX5Rx2gXiYpg2ciMnT
2026-08-27 Add touch-triggered tool lookup with OLED status
    Touching a mapped pad sends a tools/lookup request to the Pi over USB
    serial, blinks the row number on the onboard LED, and shows the tool,
    row, and exact drawer label on the Grove SSD1315 OLED. The OLED carries
    the half the row indicator cannot: row 1 spans drawers 1A/1B/1C.
    Three separate hardware bugs kept touch from ever firing, each of which
    alone looks identical to a dead pad:
    - The threshold tested for a falling reading. The ESP32-S3 uses touch
    sensor v2, where the value rises on contact. Measured on D0: ~18,300
    idle, ~31,400 touched.
    - Scanning all nine pads back-to-back froze the touch peripheral at a
    constant 2,513,860. Only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
    [smarttoolbox.ino]
2026-08-27 Put the serial tty in raw mode so the XIAO can receive replies
    Linux enumerates a ttyACM device in cooked mode with echo on. That is a
    terminal configuration and it breaks a machine protocol in both
    directions: every byte the XIAO transmits is echoed back into its own
    receive buffer, and onlcr rewrites outgoing newlines. Responses were
    lost in the echo traffic and the device timed out on every lookup.
    The failure is one-sided and hides well. The Pi logs "request id=req-8"
    and "response written id=req-8" and looks healthy, because its write
    succeeded; only the XIAO knows nothing arrived. Verified by experiment:
    five spaced commands written to the device got no reaction, and the
    first one aft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
2026-08-27 Record the hardware debugging notes from Feature 2 bring-up
    Replaces the placeholder Debugging & Testing checklist with what
    actually cost time: the service logs to files rather than the journal,
    service-error.log carries no timestamps so stale errors read as live
    ones, and a half-open serial link looks healthy from the Pi because
    "response written" only proves the write succeeded.
    Adds the lsof and stty checks that tell the two sides apart, the
    `printf "lookup ..." > /dev/ttyACM0` bench command for testing the
    device's receive path on its own, and the PowerShell reader needed
    because arduino-cli monitor exits when its output is not a terminal.
    Firmware notes gain the unbounded `while (!Se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
2026-08-27 Add the OTA firmware update endpoint (Pi side)
    GET /api/firmware/latest?currentVersion=X serves the newest image from a
    drop folder when the device is behind, and 204 when it is not.
    This is the one endpoint that can overwrite the device's firmware, so it
    does not inherit the project's "trusted home LAN, no auth" stance. It
    requires an X-Device-Key header matching DEVICE_KEY, and fails closed:
    with DEVICE_KEY unset it serves nothing and returns 503 rather than
    falling back to open access.
    The drop folder moves from the planned api/deploy/firmware/ to
    <cwd>/firmware/. sync.ps1 copies only src, public, scripts and the
    config files, so nothing under deploy/ ever reaches the Pi. The new
    locati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
2026-08-27 Add the firmware release script (OTA piece 2)
    release-firmware.ps1 stamps a version into the sketch, compiles it, and
    drops the binary where the OTA endpoint can serve it, with -Push to copy
    it to the Pi over the existing deploy key.
    The script owns both the version stamped into the sketch and the name of
    the built file. The device decides whether to update by comparing those
    two values, so letting a human set either one by hand is exactly how they
    drift apart and a device either loops on an update it already has or
    never sees one.
    The sketch gains `#define FIRMWARE_VERSION` as a single source of truth,
    replacing the version that was buried in the boot handshake's JSON string
    literal where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
    [smarttoolbox.ino]
2026-08-27 Load secrets from an untracked .env on the Pi
    smarttoolbox.service is tracked in git, so a DEVICE_KEY written into an
    Environment= line would be committed - the same mistake just fixed for
    arduino_secrets.h. The unit now reads ~/smarttoolbox/.env instead, which
    is gitignored and never copied by sync.ps1, so it survives redeploys.
    EnvironmentFile uses the '-' prefix so a missing file does not stop the
    service from starting. The OTA endpoint already fails closed on its own
    when DEVICE_KEY is absent; it should not take the whole server down with
    it.
    Adds api/deploy/.env.example as the tracked template.
2026-08-27 Add Wi-Fi OTA firmware updates (OTA piece 3)
    On boot the device joins Wi-Fi, asks the Pi whether a newer build exists,
    streams it into the inactive OTA partition, and reboots into it. Verified
    end to end: the device pulled smarttoolbox-0.4.0.bin (1,046,256 bytes)
    over Wi-Fi, wrote every byte, verified, rebooted, and reported
    currentVersion=0.4.0 on its next check. No cable involved.
    Wi-Fi is confined to setup(). The radio is switched off before loop()
    runs, so USB serial remains the only link during normal operation - the
    project's existing design is unchanged outside the update window.
    Every failure path leaves the running firmware alone. The ESP32 writes to
    the spare slot and Update.end(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
    [smarttoolbox.ino]
2026-08-27 Record the OTA and secret-verification techniques
    Four things from today that were not written down anywhere.
    Resetting the board with an RTS pulse rather than reflashing. Testing
    that an OTA update is picked up requires a clean boot that does *not*
    reflash, since flashing over USB installs the new build directly and
    proves nothing. Toggling DTR alone does not reset the board.
    The OTA test procedure, with the point that watching bytes move is not
    the proof - the next boot reporting the new version and getting a 204 is.
    HTTPClient discards response headers unless collectHeaders() is called
    before the request. It fails silently: the update still installs, it just
    cannot name the version it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
2026-08-27 Turn off TOUCH_DEBUG and fix the version regex for CRLF files
    TOUCH_DEBUG off: at roughly three lines a second it drowned the Pi's log,
    where the only interesting entries are real requests. Delivered as v0.5.0
    over the air with no cable attached - the first change to reach the
    device that way.
    The release script's version regex was anchored with '$', which in .NET
    multiline mode matches before the \n but after the \r, so it silently
    failed to find the line the moment an editor saved the sketch with
    Windows line endings. It only worked for 0.3.0 and 0.4.0 because the
    script's own WriteAllText had been preserving LF.
    Consuming the \r would have fixed the match but rewritten the line
    ending,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
    [smarttoolbox.ino]
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2026-08-27 Add the 8x8 matrix idle face and row indicator (unverified)
    The matrix is not wired, so none of this has run on hardware. It
    compiles, and matrixReady comes from the same getDeviceVID() check
    motion_ino.ino uses, so every matrix call no-ops on a box without one.
    The spec's bring-up table and the plan both say so; the status tag stays
    Blocked until it is seen working.
    Revises the plan first, because its premise was wrong. It claimed no
    driver library had been picked and that this was greenfield. In fact
    Seeed_RGB_Led_Matrix 1.0.0 is installed and motion_ino.ino already
    drives the panel - address scan, VID check, displayColorBlock. That
    removed a phase of work and answered the plan's closing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
    [smarttoolbox.ino]
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2026-08-27 Set matrix orientation explicitly and give the face a mouth
    Orientation is stored on the matrix itself and survives power cycles, so
    the panel was rendering at whatever rotation it happened to be left in -
    different between boards, and changed by any stray write. It is now set
    every boot, so "row 1" always means the same physical row. The constant
    is one edit away if the face does not sit the way up the built-in
    displayNumber() output does.
    Adds a smile below the eyes. The corners sit one row higher than the
    middle, which is what makes it read as a smile rather than a bar. The
    mouth holds still during a blink - only the eyes move.
    drawEyes is now drawFace, since it no longer draws only eye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
    [smarttoolbox.ino]
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2026-08-28 Mark the matrix done, and land the voice-lookup plan
    Matrix: the bring-up table and the plan both still said "written, never
    run". It is wired, detected, and running - idle face, and a lookup
    showing the lit row then the row digit. The plan records what the
    first-power-up checklist actually caught: the panel is mounted a quarter
    turn out, and that rotation lives on the panel itself rather than in the
    firmware, so leaving it unset meant rendering at whatever it had last
    been left in.
    Voice lookup: plan and spec corrections queued from another session.
    Checked the two factual claims before committing them - ESP_I2S.h does
    exist in the installed core 3.3.11, and recordWAV(size_t, size_t*) has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
2026-08-28 Revise the voice-lookup plan for hold-to-talk
    The recording is no longer a fixed four seconds, so its length is not known
    when the transfer starts - and a WAV header's first field is the length. The
    device sends raw PCM plus sampleRate and channels, and the Pi prepends the
    44-byte header, rather than making the device seek back and patch it.
    Records the decision to hold a touch pad instead of adding the Grove Red LED
    Button, which cannot be read where it is: it is plugged into the I2C hub,
    which has no GPIO to give it.
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2026-08-28 Answer a lookup from one location, not two arrays
    The firmware read the row from rows[0] and the drawer label from drawers[0].
    Those arrays are ordered independently: drawers comes back ordered by
    row_number ASC and SQLite sorts NULLs first, while rows skips null row numbers
    entirely. A tool recorded in both an unnumbered drawer and a numbered one
    therefore paired the numbered drawer's row with the unnumbered drawer's name.
    On a live response that read "Row 3 Drawer Odds and Ends" for a tool sitting
    in row 3 of a different drawer - confident, specific, and pointing at the
    wrong place.
    findToolLocations now returns primaryLocation, a single location object, and
    the sketch takes label, row,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
    [smarttoolbox.ino]
2026-08-28 Make observation batches, tool names, and logging behave
    Three findings from the same review. They are one commit because they
    interlock: the name-identity change forced a collation fix in code the other
    two touch, and it invalidated a test added by the reassignment work.
    Observation batches are all or nothing. Both vision paths inserted one
    detection at a time, so a batch whose third item was invalid left the first
    two committed and still answered 400. The caller saw a failure, retried, and
    doubled the rows that had already landed. recordDrawerObservations validates
    every detection and every drawer id before writing any of them, then writes
    the batch in one transaction. The HTTP and serial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
2026-08-28 Give the matrix a thinking face and two ways to say no
    A lookup could end three different ways and looked identical doing all of
    them: the same red band meant "not in any drawer", "the Pi could not make
    sense of that", and "the Pi never answered". From across a workshop those are
    the same picture, and they are not the same problem.
    Thinking: the idle face's eyes with a mouth cycling through nought to three
    dots, purple like the rest of the face. Shown from the moment the request goes
    out until something comes back - held for exactly as long as awaitingResponse
    rather than a duration, since every exit from it already sets another mode, so
    there is no timer to fall out of sync with.
    Not foun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
    [smarttoolbox.ino]
2026-08-28 Hold the row digit longer, and give thinking mismatched eyes
    Two bits of tuning from watching the states rather than reading them.
    The digit was gone before you had looked up. It is the half you actually have
    to read and carry to the box - the lit row is the spatial cue and reads
    instantly - so it gets four seconds to the row's two.
    The faces and the alert band no longer inherit that hold. They have no second
    phase and nothing to read, so they keep four seconds of their own under
    MATRIX_NOTICE_HOLD_MS rather than stretching to six because the digit needed
    The thinking face's eyes are now mismatched, the left a row taller than the
    right, which is the trick Cozmo and Vector use: two mat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
    [smarttoolbox.ino]
2026-08-29 Move row indication to the strip, and plan the mic bring-up
    Two decisions written down, and the 0.12.0 version stamp from the release
    that carried the matrix faces to the Pi.
    Row indication is going to the WS2813 strip, driven from the Pi. The matrix
    indicates a row by lighting matrix row N for toolbox row N, which has two
    faults that are the same fault from different sides: it caps at eight, because
    the unit of meaning is the panel's own height, and it is hard to read, because
    a single lit row gives the eye no scale to count against. Every fix for the
    second - a ruler column, a sweep, filling to the row - adds machinery to make
    legible a number the box should not be asking anyone to read.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
    [smarttoolbox.ino]
2026-08-29 Fit the Sense board, and pin down the microphone
    The Sense board is on, so the mic's pins stop being TBD: GPIO 42 clock, GPIO
    41 data, confirmed against Seeed's own page rather than inferred.
    The library warning already in the spec turns out to be the sharp edge here.
    That page documents core 2.x and core 3.x side by side and leads with 2.x -
    setAllPins, PDM_MONO_MODE, esp_i2s::i2s_read - none of which exists on the
    3.3.11 core this project has. Copying the wrong half of one page is now the
    likeliest first failure, so the bring-up plan says to check that before
    debugging anything else.
    Mono and 16-bit are recorded as constraints rather than settings. The S3
    supports nothing else, so they w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
2026-08-29 Let the device say it is still there, every thirty seconds
    The Pi only ever heard from the XIAO when someone used it, so the dashboard
    could not tell idle from unplugged, and the firmware version it showed was
    whatever the device had last managed to announce. On this hardware that turned
    out to be nothing at all: boot_count sat at zero through several confirmed
    reboots.
    The announcement is sent from setup(), while the USB serial port is still
    re-enumerating after a reset, so the Pi is usually mid-reconnect-backoff and
    never sees it. The journal shows it plainly - one boot has its OTA debug output
    and its device/status, the next has neither, and the only difference is timing.
    So the design n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
    [smarttoolbox.ino]
2026-08-31 Bring up the microphone, and let OTA survive a cold boot
    The microphone records on hardware for the first time: PDM I2S on GPIO 42/41,
    two seconds into PSRAM, reporting statistics rather than audio so a bad pin, a
    failed allocation and a working mic stop looking identical. Behind MIC_BRINGUP,
    which takes pad D0 over from the lookup path; set it to 0 to get the pad back.
    Three things had to be fixed to get there, and each looked like a dead mic.
    PSRAM was off in every binary this repo has ever released. A bare fqbn takes
    the first entry of each board menu, and for PSRAM that is Disabled, so
    ps_malloc returned null on every call. release-firmware.ps1 and the documented
    build commands now car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
    [smarttoolbox.ino]
2026-08-31 Wait for the Pi before claiming to be ready
    The box said Ready about thirty-three seconds before it was. Both halves boot
    from the same power and do not arrive together: this device is up in seconds,
    the Pi needs 36.6s (5.2s kernel + 31.4s userspace) before its API accepts
    anything. Every confusing symptom of yesterday lived in that window. A touch
    went into a void and painted "No response - Is the Pi service up?", which is a
    question the device is not entitled to ask while the Pi is merely booting, and
    the boot device/status went to a port nobody had open, so the dashboard showed
    no firmware version at all. The device was not broken during that window. It
    was early, and nothing distinguishe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
    [smarttoolbox.ino]
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2026-08-31 Release 0.19.0
    The reviewed build. 0.18.0 was released before the review and never reached
    the device; this replaces it as the newest in the drop folder, so that is the
    one a device pulls.
    [smarttoolbox.ino]
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2026-08-31 Hold the pad, speak, see the word
    Steps 2, 3 and 4 of PLAN-mic-bringup.md, plus the hold-to-talk the plan always
    wanted and Step 1 could not have. The plan's one-sentence scope was "hold the
    touch pad, say hammer, the OLED shows hammer"; that is what this does. No tool
    matching - turning a transcript into a drawer is PLAN-voice-lookup.md and stays
    a separate change.
    Recording is no longer a fixed two seconds taken in one blocking readBytes. It
    runs while the pad is held, read in ~100ms chunks, 300ms floor and 10s ceiling.
    The floor is because Whisper on a fragment shorter than that returns confident
    nonsense, which is worse than nothing because it looks like an answer; the
    ceiling is what b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
    [smarttoolbox.ino]
2026-08-31 Let the Pi reach the device: a command queue and a script to drive it
    The Pi could not ask the device to do anything. Getting a fresh build onto the
    XIAO meant waiting up to thirty minutes for its next scheduled check, which is
    what prompted this.
    The spec has claimed since early on that an update "can be triggered manually
    from dashboard or via serial device/ota-reset command". That command was never
    built - it sits under a Status: Implemented heading whose own text explains it
    covers a smaller build than the surrounding design, which is exactly the trap
    the status-tag convention exists to catch. That line now says what is real.
    Control is queued and collected, never sent. The protocol ha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
    [smarttoolbox.ino]
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2026-08-31 Step 3: recovered a device that answered nothing
    The step that justifies the whole plan, and the one that would have been easiest
    to skip.
    BRICK_TEST is new in the sketch, left in at 0. With it set, setup() hangs on its
    first line - before Serial.begin, before the OLED, before the OTA check. Every
    software update path this project has goes at once: no serial, no heartbeat, and
    setup() never reaches checkForFirmwareUpdate() so Wi-Fi cannot help either.
    Built as 0.99.0 and deliberately never pushed, so nothing could reach it by
    accident.
    The brick was confirmed rather than assumed. Silent from 22:01:17 to 22:03:30 -
    four missed heartbeats - with uptimeMs frozen at its pre-flash value, the
    re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
    [smarttoolbox.ino]
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2026-08-31 Say a tool, get a drawer: resolveToolQuery ships
    Phase 1 of PLAN-voice-lookup.md. The box heard you before this; now it
    understands you. "where are my needle nose pliers" returned "Tool not found" the
    day before and now resolves to Needle-Nose Pliers in row 2 - checked against the
    real toolbox, not a fixture.
    Three tiers in resolveToolQuery, first hit wins, reported as matchType. exact is
    the stored name and still runs first, so every existing test passes unchanged.
    tokens requires every meaningful query word to appear in the name, which is what
    carries a spoken sentence. partial scores word overlap but only on a distinctive
    word - without that rule "cordless drill" confidently returns whic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
    [smarttoolbox.ino]
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2026-08-31 Let the thinking face look again, by swapping which eye is tall
    A lookup that takes a while froze the face into one expression, and a frozen
    face reads as stuck rather than busy - which is this project's most expensive
    failure mode, since it asserts the box is working while it may be dead.
    Which eye is the tall one now swaps every MATRIX_THINK_SWAP_MS. 2.8s is an
    exact ten dot steps, so the two animations stay in phase instead of drifting
    against each other and turning a deliberate change into a glitch. Every lookup
    starts from the same face, so the asymmetry reads as the box looking again
    rather than as leftover state from the last query.
    The dots and the eyes run on separate clocks, so u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
    [smarttoolbox.ino]
2026-08-31 Release 0.23.1, so the thinking face reaches the box
    The face fix in 4b579ae was committed at 22:18; every binary on disk was built
    at 22:01. Nothing had ever compiled it, so the device kept running 0.23.0 and
    kept freezing its face on a slow lookup - the failure mode that change existed
    to remove.
    The version line was already stamped 0.23.1 in the working tree by hand.
    release-firmware.ps1 owns that line and rewrote it to the same value, so this
    commit records the stamp the released build was actually made from.
    Verified on hardware: bootCount 14 -> 15 and uptimeMs 5225, which is the proof
    the device rebooted into the image rather than merely reporting a new number.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
    [smarttoolbox.ino]
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2026-08-31 Stop the box misreporting its own state, and retire MIC_BRINGUP
    A review of this branch found four places where the firmware showed something
    that was not true. None of them are visible from a passing test, because none of
    them are reachable from the Pi.
    recordWhileHeld refused to break before MIC_MIN_HOLD_MS, which made the
    too-short guard below it unreachable: a 50ms brush against the pad kept
    recording to exactly the floor, returned exactly the byte count the Pi's
    MIN_AUDIO_BYTES compares against, and went off to Whisper as a word. The pad was
    then locked out for the whole round trip. The release now ends the recording
    whatever its length, and the guard fires.
    That guard was also the on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
    [smarttoolbox.ino]
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2026-10-04 Wake the box with "Hi ESP", and prove it on hardware (0.28.0)
    Saying "Hi ESP" now starts the same capture the button starts, recording a
    fixed four-second window because there is no release edge to wait for. The
    audio goes to Whisper exactly as before; nothing on the Pi changed. Proven at
    the box on 2026-10-04: "Hi ESP", then "screwdriver", transcribed and resolved.
    The phrase is not a choice. The prebuilt esp-sr in the pinned core packs one
    wake word into srmodels.bin, and that 3.3 MB blob has to sit in a partition
    named `model` - so 0.28.0 brings its own partitions.csv, with the unused
    spiffs partition gone and both OTA slots right-sized to make the room. The app
    slot is 90% full against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
    [partitions.csv]
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
